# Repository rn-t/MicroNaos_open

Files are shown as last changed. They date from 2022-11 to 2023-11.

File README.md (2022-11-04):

# MicroNaos_open
マイクロマウスというロボット競技の、クラシックマウス部門用のロボットです。



## ディレクトリ
### DXF

基板外形のDXFファイルです

### firmware
STM32向けのソースコードです。主にC++で記述しています。STM32HAL、CMSIS、SEGGER-RTTなどのライブラリも含まれています。

### PCB
機体の大部分を構成しているプリント基板及び、その回路のファイルです。Kicadを用いて作成しました
公開するにあたってライセンスの問題がないように編集を行ったため、回路シンボルが基板発注時と少し異なっています。

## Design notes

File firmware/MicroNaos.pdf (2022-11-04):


19/04/2022

MicroNaos Project
Configuration Report

## 1. Description

### 1.1. Project

Project Name | MicroNaos
Board Name | custom
Generated with: | STM32CubeMX 6.5.0
Date | 04/19/2022

### 1.2. MCU

MCU Series | STM32F4
MCU Line | STM32F405/415
MCU name | STM32F405RGTx
MCU Package | LQFP64
MCU Pin number | 64

### 1.3. Core(s) information

Core(s) | Arm Cortex-M4

## 2. Pinout Configuration

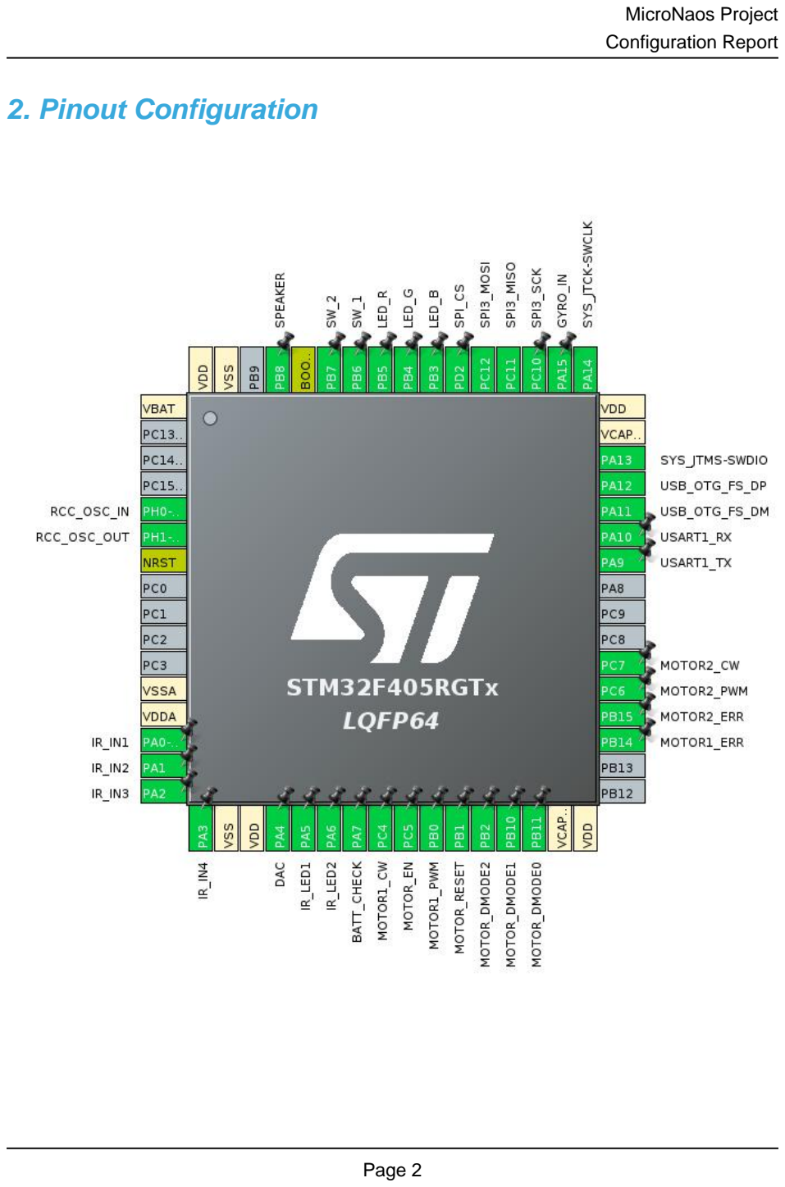
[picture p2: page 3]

## 3. Pins Configuration

Pin Number LQFP64 | Pin Name (function after reset) | Pin Type | Alternate Function(s) | Label
1 | VBAT | Power
5 | PH0-OSC_IN | I/O | RCC_OSC_IN
6 | PH1-OSC_OUT | I/O | RCC_OSC_OUT
7 | NRST | Reset
12 | VSSA | Power
13 | VDDA | Power
14 | PA0-WKUP | I/O | ADC1_IN0 | IR_IN1
15 | PA1 | I/O | ADC1_IN1 | IR_IN2
16 | PA2 | I/O | ADC1_IN2 | IR_IN3
17 | PA3 | I/O | ADC1_IN3 | IR_IN4
18 | VSS | Power
19 | VDD | Power
20 | PA4 | I/O | DAC_OUT1 | DAC
21 | PA5 | I/O | TIM2_CH1 | IR_LED1
22 | PA6 | I/O | TIM13_CH1 | IR_LED2
23 | PA7 | I/O | ADC1_IN7 | BATT_CHECK
24 | PC4 * | I/O | GPIO_Output | MOTOR1_CW
25 | PC5 * | I/O | GPIO_Output | MOTOR_EN
26 | PB0 | I/O | TIM3_CH3 | MOTOR1_PWM
27 | PB1 * | I/O | GPIO_Output | MOTOR_RESET
28 | PB2 * | I/O | GPIO_Output | MOTOR_DMODE2
29 | PB10 * | I/O | GPIO_Output | MOTOR_DMODE1
30 | PB11 * | I/O | GPIO_Output | MOTOR_DMODE0
31 | VCAP_1 | Power
32 | VDD | Power
35 | PB14 * | I/O | GPIO_Input | MOTOR1_ERR
36 | PB15 * | I/O | GPIO_Input | MOTOR2_ERR
37 | PC6 | I/O | TIM8_CH1 | MOTOR2_PWM
38 | PC7 * | I/O | GPIO_Output | MOTOR2_CW
42 | PA9 | I/O | USART1_TX
43 | PA10 | I/O | USART1_RX
44 | PA11 | I/O | USB_OTG_FS_DM
45 | PA12 | I/O | USB_OTG_FS_DP
46 | PA13 | I/O | SYS_JTMS-SWDIO
47 | VCAP_2 | Power
48 | VDD | Power

Pin Number LQFP64 | Pin Name (function after reset) | Pin Type | Alternate Function(s) | Label
49 | PA14 | I/O | SYS_JTCK-SWCLK
50 | PA15 * | I/O | GPIO_Input | GYRO_IN
51 | PC10 | I/O | SPI3_SCK
52 | PC11 | I/O | SPI3_MISO
53 | PC12 | I/O | SPI3_MOSI
54 | PD2 * | I/O | GPIO_Output | SPI_CS
55 | PB3 * | I/O | GPIO_Output | LED_B
56 | PB4 * | I/O | GPIO_Output | LED_G
57 | PB5 * | I/O | GPIO_Output | LED_R
58 | PB6 * | I/O | GPIO_Input | SW_1
59 | PB7 * | I/O | GPIO_Input | SW_2
60 | BOOT0 | Boot
61 | PB8 | I/O | TIM10_CH1 | SPEAKER
63 | VSS | Power
64 | VDD | Power

* The pin is affected with an I/O function

## 4. Clock Tree Configuration

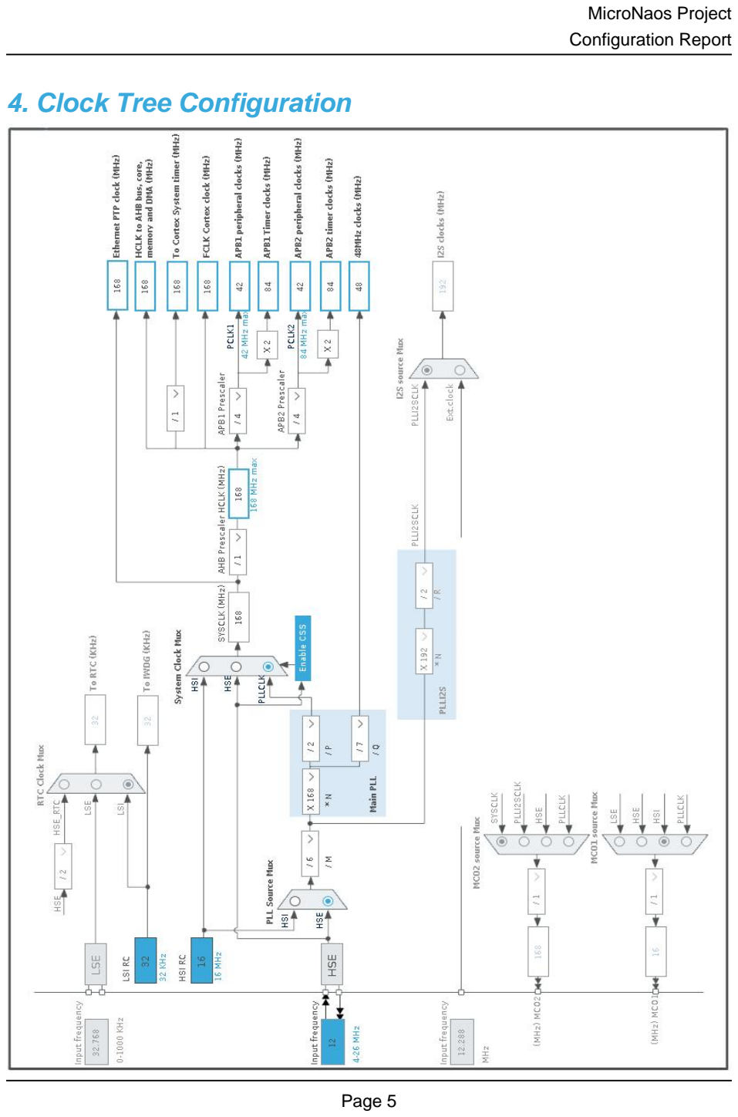
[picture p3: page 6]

## 5. Software Project

### 5.1. Project Settings

Name | Value
Project Name | MicroNaos
Project Folder | /home/hitomosi/MicroNaos/firmware
Toolchain / IDE | Makefile
Firmware Package Name and Version | STM32Cube FW_F4 V1.25.2
Application Structure | Advanced
Generate Under Root | No
Do not generate the main() | No
Minimum Heap Size | 0x200
Minimum Stack Size | 0x400

### 5.2. Code Generation Settings

Name | Value
STM32Cube MCU packages and embedded software | Copy only the necessary library files
Generate peripheral initialization as a pair of '.c/.h' files | No
Backup previously generated files when re-generating | No
Keep User Code when re-generating | Yes
Delete previously generated files when not re-generated | Yes
Set all free pins as analog (to optimize the power consumption) | No
Enable Full Assert | No

### 5.3. Advanced Settings - Generated Function Calls

Rank | Function Name | Peripheral Instance Name
1 | MX_GPIO_Init | GPIO
2 | SystemClock_Config | RCC
3 | MX_ADC1_Init | ADC1
4 | MX_DAC_Init | DAC
5 | MX_SPI3_Init | SPI3
6 | MX_TIM2_Init | TIM2
7 | MX_TIM10_Init | TIM10
8 | MX_TIM13_Init | TIM13
9 | MX_USART1_UART_Init | USART1
10 | MX_USB_DEVICE_Init | USB_DEVICE
11 | MX_TIM8_Init | TIM8

Rank | Function Name | Peripheral Instance Name
12 | MX_TIM3_Init | TIM3

## 6. Power Consumption Calculator report

### 6.1. Microcontroller Selection

Series | STM32F4
Line | STM32F405/415
MCU | STM32F405RGTx
Datasheet | DS8626_Rev8

### 6.2. Parameter Selection

Temperature | 25
Vdd | 3.3

### 6.3. Battery Selection

Battery | Li-SOCL2(A3400)
Capacity | 3400.0 mAh
Self Discharge | 0.08 %/month
Nominal Voltage | 3.6 V
Max Cont Current | 100.0 mA
Max Pulse Current | 200.0 mA
Cells in series | 1
Cells in parallel | 1

### 6.4. Sequence

Step | Step1 | Step2
Mode | RUN | STOP
Vdd | 3.3 | 3.3
Voltage Source | Battery | Battery
Range | Scale1-High | No Scale
Fetch Type | FLASH | n/a
CPU Frequency | 168 MHz | 0 Hz
Clock Configuration | HSE PLL | Regulator_LP Flash-PwrDwn
Clock Source Frequency | 4 MHz | 0 Hz
Peripherals
Additional Cons. | 0 mA | 0 mA
Average Current | 46 mA | 280 µA
Duration | 0.1 ms | 0.9 ms
DMIPS | 210.0 | 0.0
Ta Max | 98.02 | 104.96
Category | In DS Table | In DS Table

### 6.5. Results

Sequence Time | 1 ms | Average Current | 4.85 mA
Battery Life | 29 days, 4 hours | Average DMIPS | 210.0 DMIPS

### 6.6. Chart

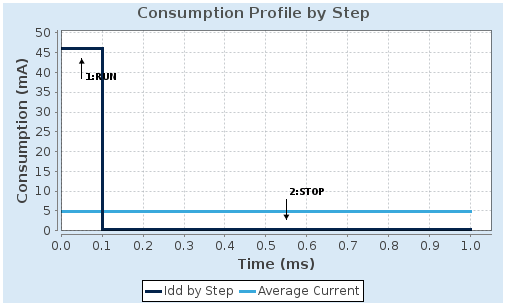
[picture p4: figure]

## 7. Peripherals and Middlewares Configuration

### 7.1. ADC1

mode: IN0
mode: IN1
mode: IN2
mode: IN3
mode: IN7
7.1.1. Parameter Settings:

ADCs_Common_Settings:

Mode | Independent mode
ADC_Settings:
Clock Prescaler | PCLK2 divided by 2
Resolution | 12 bits (15 ADC Clock cycles)
Data Alignment | Right alignment
Scan Conversion Mode | Disabled
Continuous Conversion Mode | Disabled
Discontinuous Conversion Mode | Disabled
DMA Continuous Requests | Disabled
End Of Conversion Selection | EOC flag at the end of single channel conversion
ADC_Regular_ConversionMode:
Number Of Conversion | 1
External Trigger Conversion Source | Regular Conversion launched by software
External Trigger Conversion Edge | None
Rank | 1
Channel | Channel 0
Sampling Time | 3 Cycles
ADC_Injected_ConversionMode:
Number Of Conversions | 0
WatchDog:
Enable Analog WatchDog Mode | false

### 7.2. DAC

mode: OUT1 Configuration
7.2.1. Parameter Settings:

DAC Out1 Settings:

Output Buffer | Enable
Trigger | None

### 7.3. RCC

High Speed Clock (HSE): Crystal/Ceramic Resonator
7.3.1. Parameter Settings:

System Parameters:

VDD voltage (V) | 3.3
Instruction Cache | Enabled
Prefetch Buffer | Enabled
Data Cache | Enabled
Flash Latency(WS) | 5 WS (6 CPU cycle)
RCC Parameters:
HSI Calibration Value | 16
HSE Startup Timout Value (ms) | 100
LSE Startup Timout Value (ms) | 5000
Power Parameters:
Power Regulator Voltage Scale | Power Regulator Voltage Scale 1

### 7.4. SPI3

Mode: Full-Duplex Master
7.4.1. Parameter Settings:

Basic Parameters:

Frame Format | Motorola
Data Size | 8 Bits
First Bit | MSB First
Clock Parameters:
Prescaler (for Baud Rate) | 8 *
Baud Rate | 5.25 MBits/s *
Clock Polarity (CPOL) | High *
Clock Phase (CPHA) | 2 Edge *
Advanced Parameters:
CRC Calculation | Disabled
NSS Signal Type | Software

### 7.5. SYS

Debug: Serial Wire
Timebase Source: SysTick

### 7.6. TIM2

Channel1: PWM Generation CH1
7.6.1. Parameter Settings:

Counter Settings:

Prescaler (PSC - 16 bits value) | 0
Counter Mode | Up
Counter Period (AutoReload Register - 32 bits value ) | 4294967295
Internal Clock Division (CKD) | No Division
auto-reload preload | Disable
Trigger Output (TRGO) Parameters:
Master/Slave Mode (MSM bit) | Disable (Trigger input effect not delayed)
Trigger Event Selection | Reset (UG bit from TIMx_EGR)
PWM Generation Channel 1:
Mode | PWM mode 1
Pulse (32 bits value) | 0
Output compare preload | Enable
Fast Mode | Disable
CH Polarity | High

### 7.7. TIM3

Channel3: PWM Generation CH3
7.7.1. Parameter Settings:

Counter Settings:

Prescaler (PSC - 16 bits value) | 420 - 1 *
Counter Mode | Up
Counter Period (AutoReload Register - 16 bits value ) | 1000 - 1 *
Internal Clock Division (CKD) | No Division
auto-reload preload | Disable
Trigger Output (TRGO) Parameters:

Master/Slave Mode (MSM bit) | Disable (Trigger input effect not delayed)
Trigger Event Selection | Reset (UG bit from TIMx_EGR)
PWM Generation Channel 3:
Mode | PWM mode 1
Pulse (16 bits value) | 500 - 1 *
Output compare preload | Enable
Fast Mode | Disable
CH Polarity | High

### 7.8. TIM8

Channel1: PWM Generation CH1
7.8.1. Parameter Settings:

Counter Settings:

Prescaler (PSC - 16 bits value) | 420 - 1 *
Counter Mode | Up
Counter Period (AutoReload Register - 16 bits value ) | 1000 - 1 *
Internal Clock Division (CKD) | No Division
Repetition Counter (RCR - 8 bits value) | 0
auto-reload preload | Disable
Trigger Output (TRGO) Parameters:
Master/Slave Mode (MSM bit) | Disable (Trigger input effect not delayed)
Trigger Event Selection | Reset (UG bit from TIMx_EGR)
Break And Dead Time management - BRK Configuration:
BRK State | Disable
BRK Polarity | High
Break And Dead Time management - Output Configuration:
Automatic Output State | Disable
Off State Selection for Run Mode (OSSR) | Disable
Off State Selection for Idle Mode (OSSI) | Disable
Lock Configuration | Off
PWM Generation Channel 1:
Mode | PWM mode 1
Pulse (16 bits value) | 500 - 1 *
Output compare preload | Enable
Fast Mode | Disable
CH Polarity | High
CH Idle State | Reset

### 7.9. TIM10

mode: Activated
Channel1: PWM Generation CH1
7.9.1. Parameter Settings:

Counter Settings:

Prescaler (PSC - 16 bits value) | 0
Counter Mode | Up
Counter Period (AutoReload Register - 16 bits value ) | 65535
Internal Clock Division (CKD) | No Division
auto-reload preload | Disable
PWM Generation Channel 1:
Mode | PWM mode 1
Pulse (16 bits value) | 0
Output compare preload | Enable
Fast Mode | Disable
CH Polarity | High

### 7.10. TIM13

mode: Activated
Channel1: PWM Generation CH1
7.10.1. Parameter Settings:

Counter Settings:

Prescaler (PSC - 16 bits value) | 0
Counter Mode | Up
Counter Period (AutoReload Register - 16 bits value ) | 65535
Internal Clock Division (CKD) | No Division
auto-reload preload | Disable
PWM Generation Channel 1:
Mode | PWM mode 1
Pulse (16 bits value) | 0
Output compare preload | Enable
Fast Mode | Disable
CH Polarity | High

### 7.11. USART1

Mode: Asynchronous
7.11.1. Parameter Settings:

Basic Parameters:

Baud Rate | 115200
Word Length | 8 Bits (including Parity)
Parity | None
Stop Bits | 1
Advanced Parameters:
Data Direction | Receive and Transmit
Over Sampling | 16 Samples

### 7.12. USB_OTG_FS

Mode: Device_Only
7.12.1. Parameter Settings:
Speed | Device Full Speed 12MBit/s
Low power | Disabled
Link Power Management | Disabled
VBUS sensing | Disabled
Signal start of frame | Disabled

### 7.13. USB_DEVICE

Class For FS IP: Human Interface Device Class (HID)
7.13.1. Parameter Settings:

Class Parameters:

HID_FS_BINTERVAL | 0xA *
Basic Parameters:
USBD_MAX_NUM_INTERFACES (Maximum number of supported interfaces) | 1
USBD_MAX_NUM_CONFIGURATION (Maximum number of supported configuration) | 1
USBD_MAX_STR_DESC_SIZ (Maximum size for the string descriptors) | 512
USBD_SELF_POWERED (Enabled self power) | Enabled

USBD_DEBUG_LEVEL (USBD Debug Level) | 0: No debug message
7.13.2. Device Descriptor:

Device Descriptor:

VID (Vendor IDentifier) | 1155
LANGID_STRING (Language Identifier) | English(United States)
MANUFACTURER_STRING (Manufacturer Identifier) | STMicroelectronics
Device Descriptor FS:
PID (Product IDentifier) | 22315
PRODUCT_STRING (Product Identifier) | STM32 Human interface
CONFIGURATION_STRING (Configuration Identifier) | HID Config
INTERFACE_STRING (Interface Identifier) | HID Interface

* User modified value

## 8. System Configuration

### 8.1. GPIO configuration

IP | Pin | Signal | GPIO mode | GPIO pull/up pull down | Max Speed | User Label
ADC1 | PA0-WKUP | ADC1_IN0 | Analog mode | No pull-up and no pull-down | n/a | IR_IN1
| PA1 | ADC1_IN1 | Analog mode | No pull-up and no pull-down | n/a | IR_IN2
| PA2 | ADC1_IN2 | Analog mode | No pull-up and no pull-down | n/a | IR_IN3
| PA3 | ADC1_IN3 | Analog mode | No pull-up and no pull-down | n/a | IR_IN4
| PA7 | ADC1_IN7 | Analog mode | No pull-up and no pull-down | n/a | BATT_CHECK
DAC | PA4 | DAC_OUT1 | Analog mode | No pull-up and no pull-down | n/a | DAC
RCC | PH0-OSC_IN | RCC_OSC_IN | n/a | n/a | n/a
| PH1-OSC_OUT | RCC_OSC_OUT | n/a | n/a | n/a
SPI3 | PC10 | SPI3_SCK | Alternate Function Push Pull | No pull-up and no pull-down | Very High *
| PC11 | SPI3_MISO | Alternate Function Push Pull | No pull-up and no pull-down | Very High *
| PC12 | SPI3_MOSI | Alternate Function Push Pull | No pull-up and no pull-down | Very High *
SYS | PA13 | SYS_JTMS-SWDIO | n/a | n/a | n/a
| PA14 | SYS_JTCK-SWCLK | n/a | n/a | n/a
TIM2 | PA5 | TIM2_CH1 | Alternate Function Push Pull | No pull-up and no pull-down | Low | IR_LED1
TIM3 | PB0 | TIM3_CH3 | Alternate Function Push Pull | No pull-up and no pull-down | Low | MOTOR1_PWM
TIM8 | PC6 | TIM8_CH1 | Alternate Function Push Pull | No pull-up and no pull-down | Low | MOTOR2_PWM
TIM10 | PB8 | TIM10_CH1 | Alternate Function Push Pull | No pull-up and no pull-down | Low | SPEAKER
TIM13 | PA6 | TIM13_CH1 | Alternate Function Push Pull | No pull-up and no pull-down | Low | IR_LED2
USART1 | PA9 | USART1_TX | Alternate Function Push Pull | No pull-up and no pull-down | Very High *
| PA10 | USART1_RX | Alternate Function Push Pull | No pull-up and no pull-down | Very High *
USB_OTG_ FS | PA11 | USB_OTG_FS_ DM | Alternate Function Push Pull | No pull-up and no pull-down | Very High *
| PA12 | USB_OTG_FS_ DP | Alternate Function Push Pull | No pull-up and no pull-down | Very High *
GPIO | PC4 | GPIO_Output | Output Push Pull | No pull-up and no pull-down | Low | MOTOR1_CW
| PC5 | GPIO_Output | Output Push Pull | No pull-up and no pull-down | Low | MOTOR_EN
| PB1 | GPIO_Output | Output Push Pull | No pull-up and no pull-down | Low | MOTOR_RESET

IP | Pin | Signal | GPIO mode | GPIO pull/up pull down | Max Speed | User Label
| PB2 | GPIO_Output | Output Push Pull | No pull-up and no pull-down | Low | MOTOR_DMODE2
| PB10 | GPIO_Output | Output Push Pull | No pull-up and no pull-down | Low | MOTOR_DMODE1
| PB11 | GPIO_Output | Output Push Pull | No pull-up and no pull-down | Low | MOTOR_DMODE0
| PB14 | GPIO_Input | Input mode | No pull-up and no pull-down | n/a | MOTOR1_ERR
| PB15 | GPIO_Input | Input mode | No pull-up and no pull-down | n/a | MOTOR2_ERR
| PC7 | GPIO_Output | Output Push Pull | No pull-up and no pull-down | Low | MOTOR2_CW
| PA15 | GPIO_Input | Input mode | No pull-up and no pull-down | n/a | GYRO_IN
| PD2 | GPIO_Output | Output Push Pull | No pull-up and no pull-down | Low | SPI_CS
| PB3 | GPIO_Output | Output Push Pull | No pull-up and no pull-down | Low | LED_B
| PB4 | GPIO_Output | Output Push Pull | No pull-up and no pull-down | Low | LED_G
| PB5 | GPIO_Output | Output Push Pull | No pull-up and no pull-down | Low | LED_R
| PB6 | GPIO_Input | Input mode | Pull-up * | n/a | SW_1
| PB7 | GPIO_Input | Input mode | Pull-up * | n/a | SW_2

### 8.2. DMA configuration

nothing configured in DMA service

### 8.3. NVIC configuration

8.3.1. NVIC
Interrupt Table | Enable | Preenmption Priority | SubPriority
Non maskable interrupt | true | 0 | 0
Hard fault interrupt | true | 0 | 0
Memory management fault | true | 0 | 0
Pre-fetch fault, memory access fault | true | 0 | 0
Undefined instruction or illegal state | true | 0 | 0
System service call via SWI instruction | true | 0 | 0
Debug monitor | true | 0 | 0
Pendable request for system service | true | 0 | 0
System tick timer | true | 0 | 0
TIM3 global interrupt | true | 0 | 0
TIM8 break interrupt and TIM12 global interrupt | true | 0 | 0
TIM8 update interrupt and TIM13 global interrupt | true | 0 | 0
TIM8 trigger and commutation interrupts and TIM14 global interrupt | true | 0 | 0
TIM8 capture compare interrupt | true | 0 | 0
USB On The Go FS global interrupt | true | 0 | 0
PVD interrupt through EXTI line 16 | unused
Flash global interrupt | unused
RCC global interrupt | unused
ADC1, ADC2 and ADC3 global interrupts | unused
TIM1 update interrupt and TIM10 global interrupt | unused
TIM2 global interrupt | unused
USART1 global interrupt | unused
SPI3 global interrupt | unused
TIM6 global interrupt, DAC1 and DAC2 underrun error interrupts | unused
FPU global interrupt | unused
8.3.2. NVIC Code generation
Enabled interrupt Table | Select for init sequence ordering | Generate IRQ handler | Call HAL handler
Non maskable interrupt | false | true | false
Hard fault interrupt | false | true | false
Memory management fault | false | true | false
Pre-fetch fault, memory access fault | false | true | false
Undefined instruction or illegal state | false | true | false

Enabled interrupt Table | Select for init sequence ordering | Generate IRQ handler | Call HAL handler
System service call via SWI instruction | false | true | false
Debug monitor | false | true | false
Pendable request for system service | false | true | false
System tick timer | false | true | true
TIM3 global interrupt | false | true | true
TIM8 break interrupt and TIM12 global interrupt | false | true | true
TIM8 update interrupt and TIM13 global interrupt | false | true | true
TIM8 trigger and commutation interrupts and TIM14 global interrupt | false | true | true
TIM8 capture compare interrupt | false | true | true
USB On The Go FS global interrupt | false | true | true

* User modified value

## 9. System Views

9.1. Category view
9.1.1. Current

## 10. Docs & Resources

Type | Link
Presentations | https://www.st.com/resource/en/product_presentation/stm32-stm8_embedded_software_solutions.pdf
Presentations | https://www.st.com/resource/en/product_presentation/stm32_eval-tools_portfolio.pdf
Presentations | https://www.st.com/resource/en/product_presentation/stm32_stm8_functi onal-safety-packages.pdf
Presentations | https://www.st.com/resource/en/product_presentation/stm32-stm8_software_development_tools.pdf
Training Material | https://www.st.com/resource/en/sales_guide/sg_sc2154.pdf
Flyers | https://www.st.com/resource/en/flyer/flnucleolrwan.pdf
Flyers | https://www.st.com/resource/en/flyer/flstm32nucleo.pdf
Flyers | https://www.st.com/resource/en/flyer/flstmcsuite.pdf
Flyers | https://www.st.com/resource/en/flyer/flstm32trust.pdf
Product Certifications | https://www.st.com/resource/en/certification_document/stm32_authentication_can.pdf
Application Notes | https://www.st.com/resource/en/application_note/an1181-electrostatic-discharge-sensitivity-measurement-stmicroelectronics.pdf
Application Notes | https://www.st.com/resource/en/application_note/an1709-emc-design-guide-for-stm8-stm32-and-legacy-mcus-stmicroelectronics.pdf
Application Notes | https://www.st.com/resource/en/application_note/an2606-stm32-microcontroller-system-memory-boot-mode-stmicroelectronics.pdf
Application Notes | https://www.st.com/resource/en/application_note/an2639-soldering-recommendations-and-package-information-for-leadfree-ecopack-mcus-and-mpus-stmicroelectronics.pdf
Application Notes | https://www.st.com/resource/en/application_note/an2834-how-to-get-the-best-adc-accuracy-in-stm32-microcontrollers-stmicroelectronics.pdf
Application Notes | https://www.st.com/resource/en/application_note/an2867-oscillator-design-guide-for-stm8afals-stm32-mcus-and-mpus-stmicroelectronics.pdf
Application Notes | https://www.st.com/resource/en/application_note/an2945-stm8s-and-

| stm32-mcus-a-consistent-832bit-product-line-for-painless-migration-stmicroelectronics.pdf
Application Notes | https://www.st.com/resource/en/application_note/an3070-managing-the-driver-enable-signal-for-rs485-and-iolink-communications-with-the-stm32s-usart-stmicroelectronics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
Application Notes | https://www.st.com/resource/en/application_note/an3126-audio-and-waveform-generation-using-the-dac-in-stm32-products-stmicroelectronics.pdf
Application Notes | https://www.st.com/resource/en/application_note/an3154-can-protocol-used-in-the-stm32-bootloader-stmicroelectronics.pdf
Application Notes | https://www.st.com/resource/en/application_note/an3155-usart-protocol-used-in-the-stm32-bootloader-stmicroelectronics.pdf
Application Notes | https://www.st.com/resource/en/application_note/an3156-usb-dfu-protocol-used-in-the-stm32-bootloader-stmicroelectronics.pdf
Application Notes | https://www.st.com/resource/en/application_note/an3364-migration-and-compatibility-guidelines-for-stm32-microcontroller-applications-stmicroelectronics.pdf
Application Notes | https://www.st.com/resource/en/application_note/an3371-using-the-hardware-realtime-clock-rtc-in-stm32-f0-f2-f3-f4-and-l1-series-of-mcus-stmicroelectronics.pdf
Application Notes | https://www.st.com/resource/en/application_note/an3997-audio-playback-and-recording-using-the-stm32f4discovery-stmicroelectronics.pdf
Application Notes | https://www.st.com/resource/en/application_note/an3998-pdm-audio-software-decoding-on-stm32-microcontrollers-stmicroelectronics.pdf
Application Notes | https://www.st.com/resource/en/application_note/an4013-stm32-crossseries-timer-overview-stmicroelectronics.pdf
Application Notes | https://www.st.com/resource/en/application_note/an4031-using-the-stm32f2-stm32f4-and-stm32f7-series-dma-controller-stmicroelectronics.pdf
Application Notes | https://www.st.com/resource/en/application_note/an4073-how-to-improve-adc-accuracy-when-using-stm32f2xx-and-stm32f4xx-microcontrollers-stmicroelectronics.pdf
Application Notes | https://www.st.com/resource/en/application_note/an4076-two-or-three-

| shunt-resistor-based-current-sensing-circuit-design-in-3phase-inverters-stmicroelectronics.pdf
Application Notes | https://www.st.com/resource/en/application_note/an4221-i2c-protocol-used-in-the-stm32-bootloader-stmicroelectronics.pdf
Application Notes | https://www.st.com/resource/en/application_note/an4229-how-to-implement-a-vocoder-solution-using-stm32-microcontrollers-stmicroelectronics.pdf
Application Notes | https://www.st.com/resource/en/application_note/an4230-stm32-microcontroller-random-number-generation-validation-using-the-nist-statistical-test-suite-stmicroelectro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
Application Notes | https://www.st.com/resource/en/application_note/an4277-using-stm32-device-pwm-shutdown-features-for-motor-control-and-digital-power-conversion-stmicroelectronics.pdf
Application Notes | https://www.st.com/resource/en/application_note/an4286-spi-protocol-used-in-the-stm32-bootloader-stmicroelectronics.pdf
Application Notes | https://www.st.com/resource/en/application_note/an4488-getting-started-with-stm32f4xxxx-mcu-hardware-development-stmicroelectronics.pdf
Application Notes | https://www.st.com/resource/en/application_note/an4566-extending-the-dac-performance-of-stm32-microcontrollers-stmicroelectronics.pdf
Application Notes | https://www.st.com/resource/en/application_note/an4640-peripherals-interconnections-on-stm32f4057xx-stm32f4157xx-stm32f42xxx-stm32f43xxx-stm32f446xx-and-stm32f469479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
Application Notes | https://www.st.com/resource/en/application_note/an4655-virtually-increasing-the-number-of-serial-communication-peripherals-in-stm32-applications-stmicroelectronics.p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
Application Notes | https://www.st.com/resource/en/application_note/an4739-stm32cube-firmware-examples-for-stm32f4-series-stmicroelectronics.pdf
Application Notes | https://www.st.com/resource/en/application_note/an4750-handling-of-soft-errors-in-stm32-applications-stmicroelectronics.pdf
Application Notes | https://www.st.com/resource/en/application_note/an4759-using-the-hardware-realtime-clock-rtc-and-the-tamper-management-unit-tamp-with-stm32-microcontrollers-stmicroe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
Application Notes | https://www.st.com/resource/en/application_note/an4776-generalpurpose-

| timer-cookbook-for-stm32-microcontrollers-stmicroelectronics.pdf
Application Notes | https://www.st.com/resource/en/application_note/an4803-highspeed-si-simulations-using-ibis-and-boardlevel-simulations-using-hyperlynx-si-on-stm32-mcus-and-mpus-stmic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
Application Notes | https://www.st.com/resource/en/application_note/an4821-migrating-from-stm32f405415-line-and-stm32f407417-line-to-stm32l4-series-and-stm32l4-series-microcontrollers-s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
Application Notes | https://www.st.com/resource/en/application_note/an4838-managing-memory-protection-unit-in-stm32-mcus-stmicroelectronics.pdf
Application Notes | https://www.st.com/resource/en/application_note/an4850-stm32-mcus-spreadspectrum-clock-generation-principles-properties-and-implementation-stmicroelectronics.pdf
Application Notes | https://www.st.com/resource/en/application_note/an4879-usb-hardware-and-pcb-guidelines-using-stm32-mcus-stmicroelectronics.pdf
Application Notes | https://www.st.com/resource/en/application_note/an4908-stm32-usart-automatic-baud-rate-detection-stmicroelectronics.pdf
Application Notes | https://www.st.com/resource/en/application_note/an4989-stm32-microcontroller-debug-toolbox-stmicroelectronics.pdf
Application Notes | https://www.st.com/resource/en/application_note/an4995-using-an-electromyogram-technique-to-detect-muscle-activity-stmicroelectronics.pdf
Application Notes | https://www.st.com/resource/en/application_note/an5027-interfacing-pdm-digital-microphones-using-stm32-mcus-and-mpus-stmicroelectronics.pdf
Application Notes | https://www.st.com/resource/en/application_note/an5036-thermal-management-guidelines-for-stm32-applications-stmicroelectronics.pdf
Application Notes | https://www.st.com/resource/en/application_note/an5073-receiving-spdif-audio-stream-with-the-stm32f4f7h7-series-stmicroelectronics.pdf
Application Notes | https://www.st.com/resource/en/application_note/an5156-introduction-to-stm32-microcontrollers-security-stmicroelectronics.pdf
Application Notes | https://www.st.com/resource/en/application_note/an5225-usb-typec-power-delivery-using-stm32-mcus-and-mpus-stmicroelectronics.pdf
Application Notes | https://www.st.com/resource/en/application_note/an5543-enhanced- methods-to-handle-spi-communication-on-stm32-devices-

| stmicroelectronics.pdf
Application Notes | https://www.st.com/resource/en/application_note/an4899-stm32-microcontroller-gpio-configuration-for-hardware-settings-and-lowpower-consumption-stmicroelectronics.pdf
Application Notes for related Tools & Software | https://www.st.com/resource/en/application_note/an1202_freertos_guide-freertos-guide-stmicroelectronics.pdf
Application Notes for related Tools & Software | https://www.st.com/resource/en/application_note/an1602_semihosting_in_truestudio-how-to-do-semihosting-in-truestudio-stmicroelectronics.pdf
Application Notes for related Tools & Software | https://www.st.com/resource/en/application_note/an1801_stm32cubeprogrammer_in_truestudio-installing-stm32cubeprogrammer-in-truestudio-stmicroelectronics.pdf
Application Notes for related Tools & Software | https://www.st.com/resource/en/application_note/atollic_editing_keyboard_shortcuts-atollic-editing-keyboard-shortcuts-stmicroelectronics.pdf
Application Notes for related Tools & Software | https://www.st.com/resource/en/application_note/iar_to_atollic_truestudio_migration_guide-truestudio-for-arm-migration-guide-iar-embedded-workbench-to-truestudio-stm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
Application Notes for related Tools & Software | https://www.st.com/resource/en/application_note/stm32cubemx_installation_in_truestudio-stm32cubemx-installation-in-truestudio-stmicroelectronics.pdf
Application Notes for related Tools & Software | https://www.st.com/resource/en/application_note/an2656-stm32f10xxx-lcd-glass-driver-firmware-stmicroelectronics.pdf
Application Notes for related Tools & Software | https://www.st.com/resource/en/application_note/an2790-tft-lcd-interfacing-with-the-highdensity-stm32f10xxx-fsmc-stmicroelectronics.pdf
Application Notes for related Tools & Software | https://www.st.com/resource/en/application_note/an3078-stm32-inapplication-programming-over-the-ic-bus-stmicroelectronics.pdf
Application Notes for related Tools & Software | https://www.st.com/resource/en/application_note/an3116-stm32s-adc-modes-and-their-applications-stmicroelectronics.pdf

Application Notes for related Tools & Software | https://www.st.com/resource/en/application_note/an3174-implementing-receivers-for-infrared-remote-control-protocols-using-stm32f10xxx-microcontrollers-stmicroelectro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
Application Notes for related Tools & Software | https://www.st.com/resource/en/application_note/an3241-qvga-tftlcd-direct-drive-using-the-stm32f10xx-fsmc-peripheral-stmicroelectronics.pdf
Application Notes for related Tools & Software | https://www.st.com/resource/en/application_note/an3307-guidelines-for-obtaining-iec-60335-class-b-certification-for-any-stm32-application-stmicroelectronics.pdf
Application Notes for related Tools & Software | https://www.st.com/resource/en/application_note/an3364-migration-and-compatibility-guidelines-for-stm32-microcontroller-applications-stmicroelectronics.pdf
Application Notes for related Tools & Software | https://www.st.com/resource/en/application_note/an3965-stm32f40xstm32f41x-inapplication-programming-using-the-usart-stmicroelectronics.pdf
Application Notes for related Tools & Software | https://www.st.com/resource/en/application_note/an3969-eeprom-emulation-in-stm32f40xstm32f41x-microcontrollers-stmicroelectronics.pdf
Application Notes for related Tools & Software | https://www.st.com/resource/en/application_note/an3988-clock-configuration-tool-for-stm32f40xx41xx427x437x-microcontrollers-stmicroelectronics.pdf
Application Notes for related Tools & Software | https://www.st.com/resource/en/application_note/an3990-upgrading-stm32f4discovery-board-firmware-using-a-usb-key-stmicroelectronics.pdf
Application Notes for related Tools & Software | https://www.st.com/resource/en/application_note/an3997-audio-playback-and-recording-using-the-stm32f4discovery-stmicroelectronics.pdf
Application Notes for related Tools & Software | https://www.st.com/resource/en/application_note/an3998-pdm-audio-software-decoding-on-stm32-microcontrollers-stmicroelectronics.pdf
Application Notes for related Tools & Software | https://www.st.com/resource/en/application_note/an4044-floating-point-unit-demonstration-on-stm32-microcontrollers-stmicroelectronics.pdf
Application Notes | https://www.st.com/resource/en/application_note/an4187-using-the-crc-

for related Tools & Software | peripheral-in-the-stm32-family-stmicroelectronics.pdf
Application Notes for related Tools & Software | https://www.st.com/resource/en/application_note/an4323-getting-started-with-stemwin-library-stmicroelectronics.pdf
Application Notes for related Tools & Software | https://www.st.com/resource/en/application_note/an4365-using-stm32f4-mcu-power-modes-with-best-dynamic-efficiency-stmicroelectronics.pdf
Application Notes for related Tools & Software | https://www.st.com/resource/en/application_note/an4435-guidelines-for-obtaining-ulcsaiec-607301603351-class-b-certification-in-any-stm32-application-stmicroelectroni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
Application Notes for related Tools & Software | https://www.st.com/resource/en/application_note/an4457-implementing-an-emulated-uart-on-stm32f4-microcontrollers-stmicroelectronics.pdf
Application Notes for related Tools & Software | https://www.st.com/resource/en/application_note/an4499-stm32--nrf51822-bluetooth-low-energy-system-solution-stmicroelectronics.pdf
Application Notes for related Tools & Software | https://www.st.com/resource/en/application_note/an4502-stm32-smbuspmbus-embedded-software-expansion-for-stm32cube-stmicroelectronics.pdf
Application Notes for related Tools & Software | https://www.st.com/resource/en/application_note/an4657-stm32-inapplication-programming-iap-using-the-usart-stmicroelectronics.pdf
Application Notes for related Tools & Software | https://www.st.com/resource/en/application_note/an4666-parallel-synchronous-transmission-using-gpio-and-dma-stmicroelectronics.pdf
Application Notes for related Tools & Software | https://www.st.com/resource/en/application_note/an4678-full-duplex-spi-emulation-for-stm32f4-microcontrollers-stmicroelectronics.pdf
Application Notes for related Tools & Software | https://www.st.com/resource/en/application_note/an4701-proprietary-code-readout-protection-on-microcontrollers-of-the-stm32f4-series-stmicroelectronics.pdf

Application Notes
for related Tools

https://www.st.com/resource/en/application_note/an4739-stm32cubefirmware-examples-for-stm32f4-series-stmicroelectronics.pdf

& Software
Application Notes for related Tools & Software | https://www.st.com/resource/en/application_note/an4758-proprietary-code-readout-protection-on-stm32l4-stm32l4-stm32g4-and-stm32wb-series-mcus-stmicroelectronics.pdf
Application Notes for related Tools & Software | https://www.st.com/resource/en/application_note/an4759-using-the-hardware-realtime-clock-rtc-and-the-tamper-management-unit-tamp-with-stm32-microcontrollers-stmicroe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
Application Notes for related Tools & Software | https://www.st.com/resource/en/application_note/an4841-digital-signal-processing-for-stm32-microcontrollers-using-cmsis-stmicroelectronics.pdf
Application Notes for related Tools & Software | https://www.st.com/resource/en/application_note/an4968-proprietary-code-read-out-protection-pcrop-on-stm32f72xxx-and-stm32f73xxx-microcontrollers-stmicroelectronics.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
Application Notes for related Tools & Software | https://www.st.com/resource/en/application_note/an5054-secure-programming-using-stm32cubeprogrammer-stmicroelectronics.pdf
Application Notes for related Tools & Software | https://www.st.com/resource/en/application_note/an5056-integration-guide-for-the-xcubesbsfu-stm32cube-expansion-package-stmicroelectronics.pdf
Application Notes for related Tools & Software | https://www.st.com/resource/en/application_note/an5143-how-to-migrate-motor-control-application-software-from-sdk-v43-to-sdk-v5x-stmicroelectronics.pdf
Application Notes for related Tools & Software | https://www.st.com/resource/en/application_note/an5166-guidelines-for-control-and-customization-of-power-boards-with-stm32-mc-sdk-v50-stmicroelectronics.pdf
Application Notes for related Tools & Software | https://www.st.com/resource/en/application_note/an5360-getting-started-with-projects-based-on-the-stm32mp1-series-in-stm32cubeide-stmicroelectronics.pdf
Application Notes for related Tools & Software | https://www.st.com/resource/en/application_note/an5361-getting-started-with-projects-based-on-dualcore-stm32h7-microcontrollers-in-stm32cubeide-stmicroelectronics.pd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
Application Notes for related Tools & Software | https://www.st.com/resource/en/application_note/an5394-getting-started-with-projects-based-on-the-stm32l5-series-in-stm32cubeide-stmicroelectronics.pdf

Application Notes for related Tools & Software | https://www.st.com/resource/en/application_note/an5418-how-to-build-a-simple-usbpd-sink-application-with-stm32cubemx-stmicroelectronics.pdf
Application Notes for related Tools & Software | https://www.st.com/resource/en/application_note/an5426-migrating-graphics-middleware-projects-from-stm32cubemx-540-to-stm32cubemx-550-stmicroelectronics.pdf
Application Notes for related Tools & Software | https://www.st.com/resource/en/application_note/an5464-position-control-of-a-threephase-permanent-magnet-motor-using-xcubemcsdk-or-xcubemcsdkful-stmicroelectronics.p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
Application Notes for related Tools & Software | https://www.st.com/resource/en/application_note/an5564-getting-started-with-projects-based-on-dualcore-stm32wl-microcontrollers-in-stm32cubeide-stmicroelectronics.pd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
Application Notes for related Tools & Software | https://www.st.com/resource/en/application_note/an5698-adapting-the-xcubestl-functional-safety-package-for-stm32-iec-61508-compliant-to-other-safety-standards-stmicr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
Application Notes for related Tools & Software | https://www.st.com/resource/en/application_note/an5731-stm32cubemx-and-stm32cubeide-threadsafe-solution-stmicroelectronics.pdf
Errata Sheets | https://www.st.com/resource/en/errata_sheet/es0182-stm32f405407xx-and-stm32f415417xx-device-limitations-stmicroelectronics.pdf
Datasheet | https://www.st.com/resource/en/datasheet/dm00037051.pdf
Programming Manuals | https://www.st.com/resource/en/programming_manual/pm0214-stm32-cortexm4-mcus-and-mpus-programming-manual-stmicroelectronics.pdf
Reference Manuals | https://www.st.com/resource/en/reference_manual/rm0090-stm32f405415-stm32f407417-stm32f427437-and-stm32f429439-advanced-armbased-32bit-mcus-stmicroelectronics.pdf
Technical Notes & Articles | https://www.st.com/resource/en/technical_note/tn0516-overview-of-the-stm32f0xf100xxf103xx-and-stm32f2xxf30xf4xx-mcus-pmsm-singledual-foc-sdk-v40-stmicroelectronics.p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
Technical Notes & Articles | https://www.st.com/resource/en/technical_note/tn1163-description-of-wlcsp-for-microcontrollers-and-recommendations-for-its-use-stmicroelectronics.pdf

Technical Notes
& Articles

https://www.st.com/resource/en/technical_note/tn1204-tape-and-reelshipping-media-for-stm32-microcontrollers-in-bga-packages-

| stmicroelectronics.pdf
Technical Notes & Articles | https://www.st.com/resource/en/technical_note/tn1205-tape-and-reel-shipping-media-for-stm8-and-stm32-microcontrollers-in-fpn-packages-stmicroelectronics.pdf
Technical Notes & Articles | https://www.st.com/resource/en/technical_note/tn1206-tape-and-reel-shipping-media-for-stm8-and-stm32-microcontrollers-in-qfp-packages-stmicroelectronics.pdf
Technical Notes & Articles | https://www.st.com/resource/en/technical_note/tn1207-tape-and-reel-shipping-media-for-stm8-and-stm32-microcontrollers-in-so-packages-stmicroelectronics.pdf
Technical Notes & Articles | https://www.st.com/resource/en/technical_note/tn1208-tape-and-reel-shipping-media-for-stm8-and-stm32-microcontrollers-in-tssop-and-ssop-packages-stmicroelectronics.p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

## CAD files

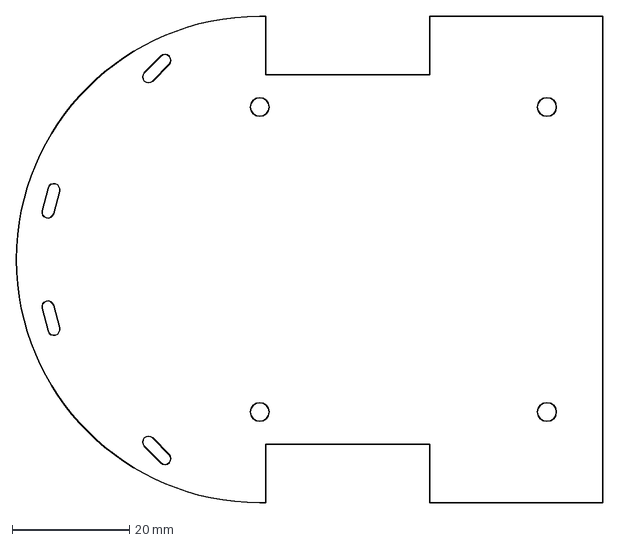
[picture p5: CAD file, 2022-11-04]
DXF/Kiban.dxf
100.0 x 83.0 mm

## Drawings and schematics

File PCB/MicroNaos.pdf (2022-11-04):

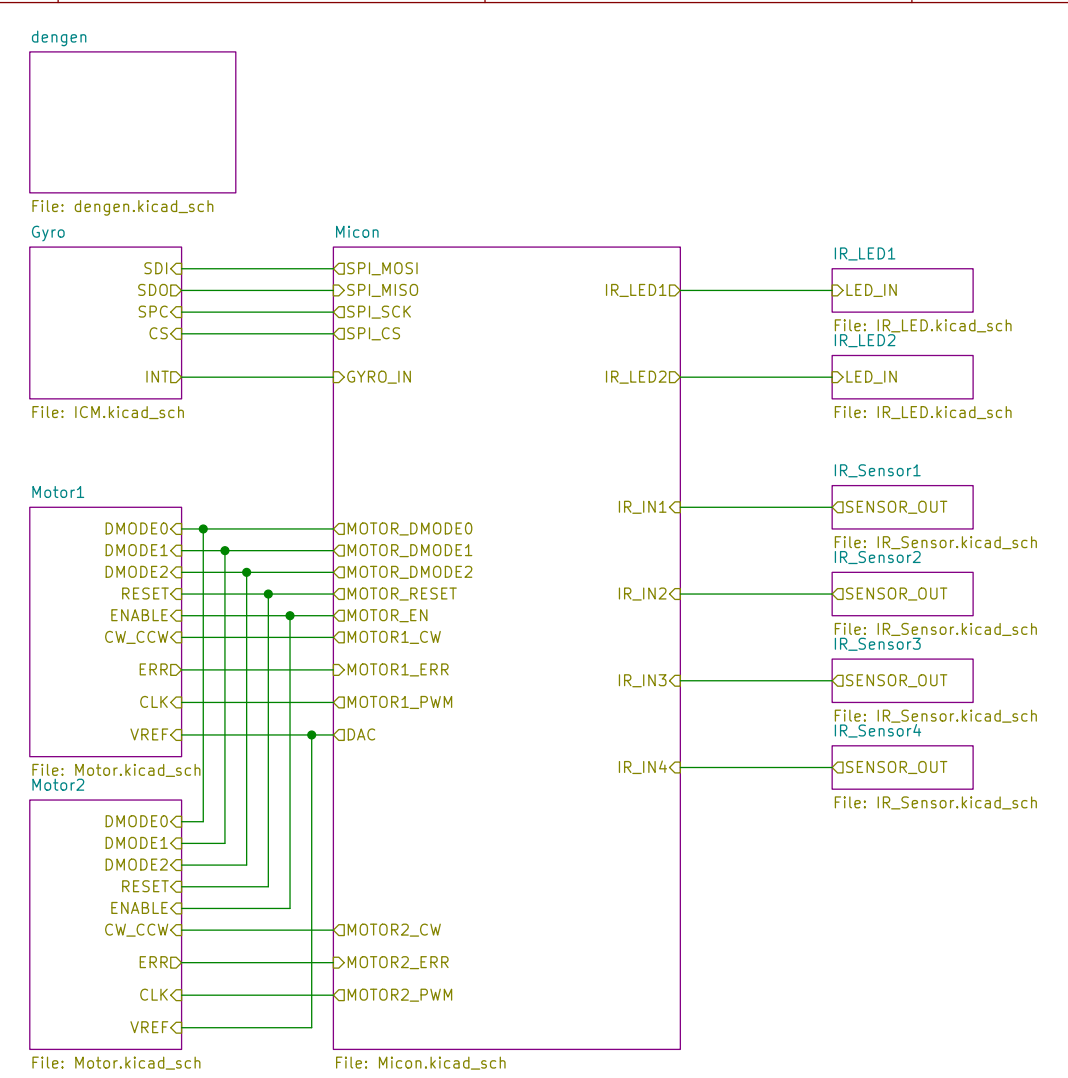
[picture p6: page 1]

INT CS Gyro File: ICM.kicad_sch VREF DMODE0 DMODE1 DMODE2 RESET CLK

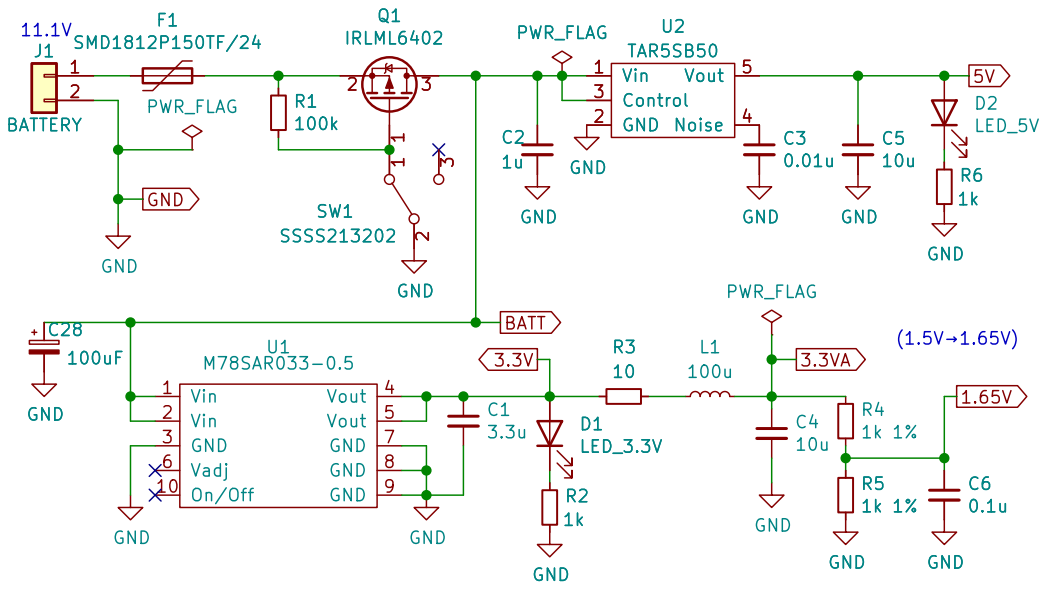
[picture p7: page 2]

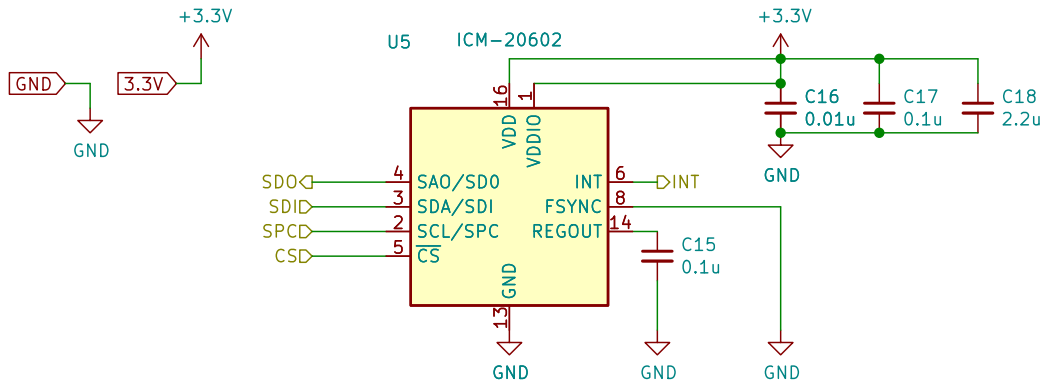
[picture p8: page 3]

1 GND 13 REGOUT 14 VDD 16 SCL/SPC 2 SDA/SDI 3 SAO/SD0 4 ~{CS} 5

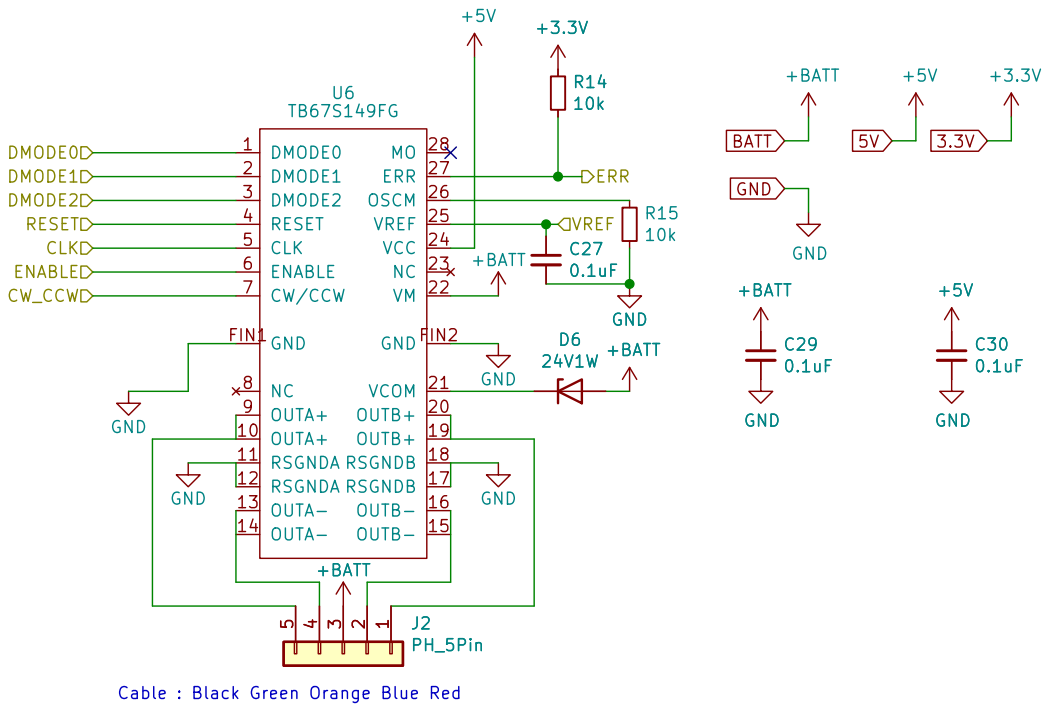
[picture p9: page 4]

BATT Cable : Black Green Orange Blue Red

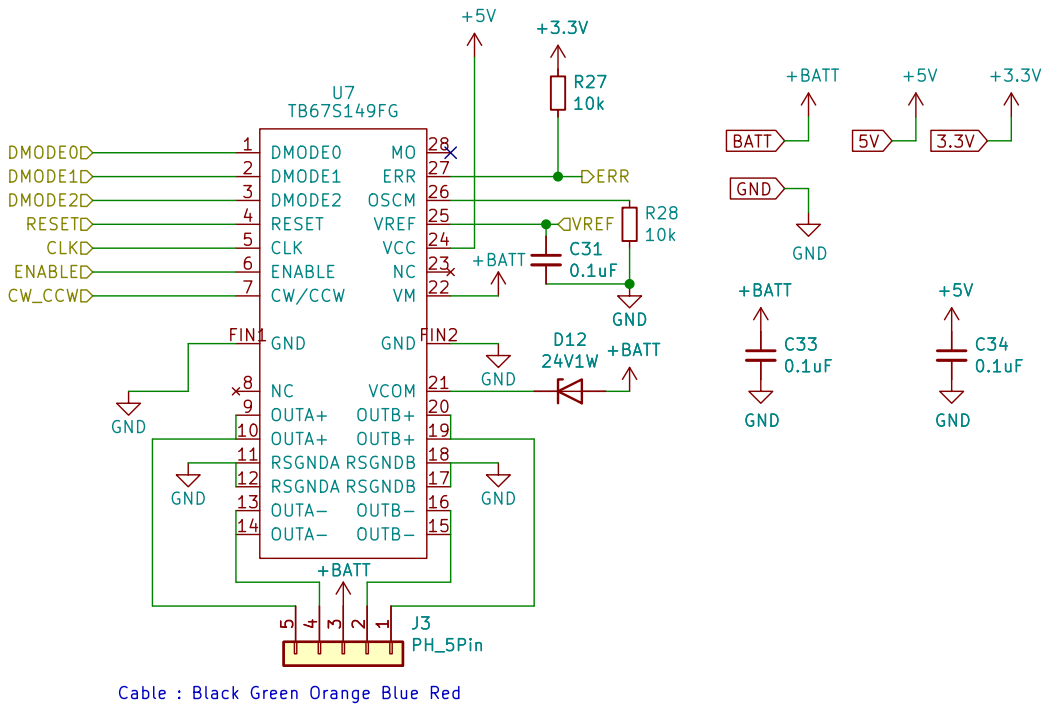
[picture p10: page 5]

BATT Cable : Black Green Orange Blue Red

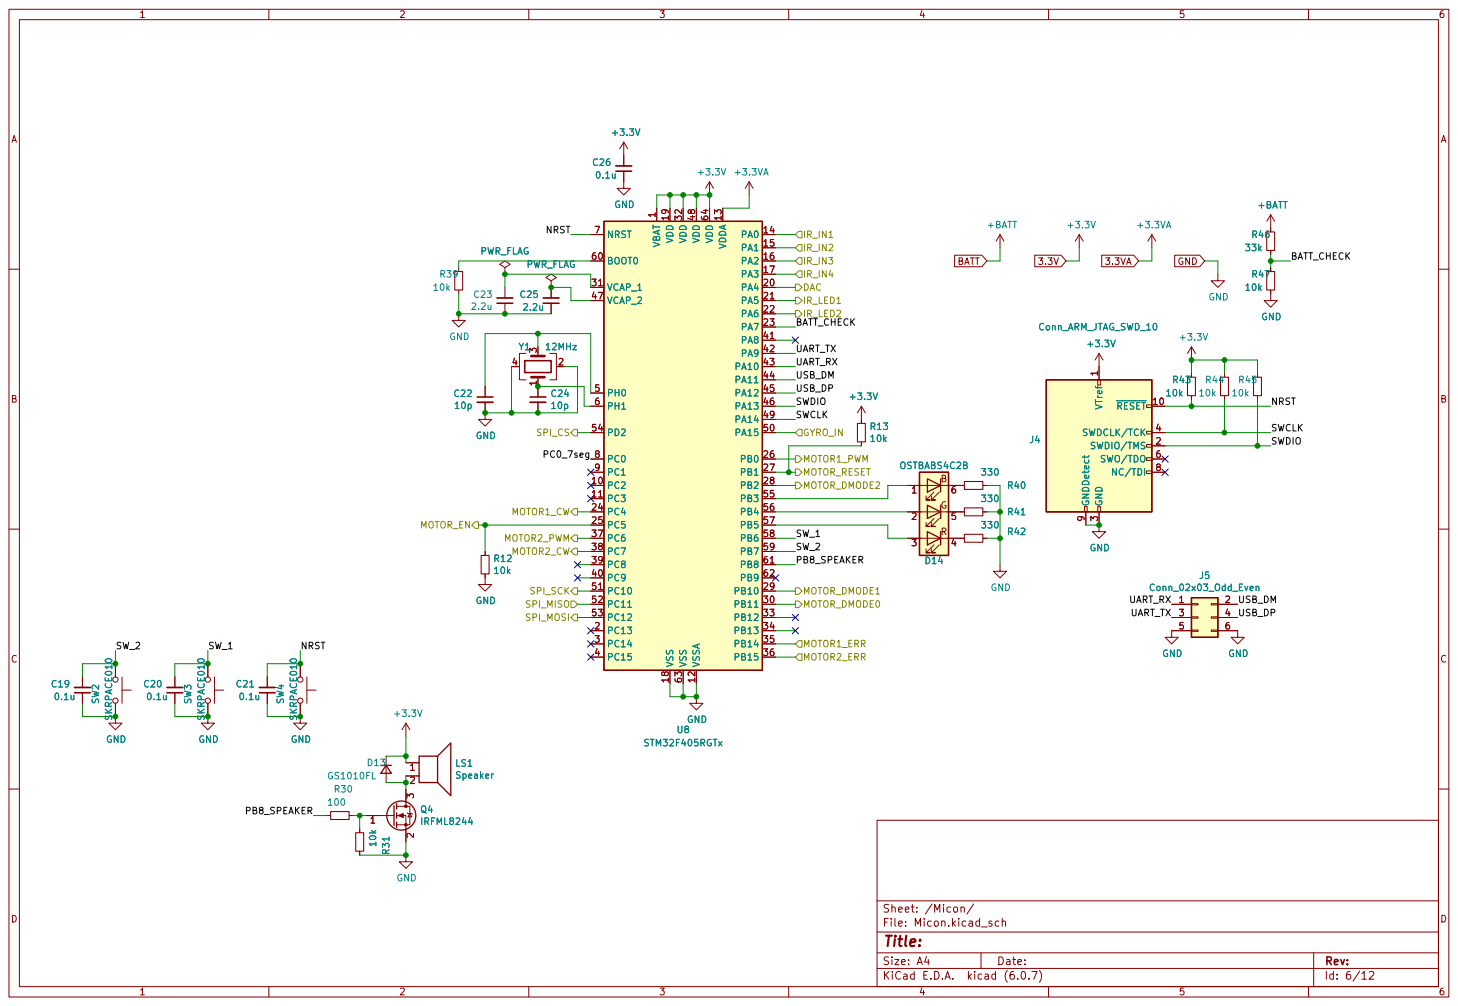
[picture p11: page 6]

1 PC2 10 PC3 11 VSSA 12 VDDA 13 PA0 14 PA1 15 PA2 16 PA3 17 VSS 18 VDD 19 PC13 2 PA4 20 PA5 21 PA6 22 PA7 23 PC4 24 PC5 25 PB0 26 PB1 27 PB2 28 PB10 29 PC14 3 PB11 30 VCAP_1 31 VDD 32 PB12 33 PB13 34 PB14 35 PB15 36 PC6 37 PC7 38 PC8 39 PC15 4 PC9 40 PA8 41 PA9 42 PA10 43 PA11 44 PA12 45 PA13 46 VCAP_2 47 VDD 48 PA14 49 PH0 5 PA15 50 PC10 51 PC11 52 PC12 53 PD2 54 PB3 55 PB4 56 PB5 57 PB6 58 PB7 59 PH1 6 BOOT0 60 PB8 61 PB9 62 VSS 63 VDD 64 NRST 7 PC0 8 PC1 9 U8 STM32F405RGTx

1 PC2 10 PC3 11 VSSA 12 VDDA 13 PA0 14 PA1 15 PA2 16 PA3 17 VSS 18 VDD 19 PC13 2 PA4 20 PA5 21 PA6 22 PA7 23 PC4 24 PC5 25 PB0 26 PB1 27 PB2 28 PB10 29 PC14 3 PB11 30 VCAP_1 31 VDD 32 PB12 33 PB13 34 PB14 35 PB15 36 PC6 37 PC7 38 PC8 39 PC15 4 PC9 40 PA8 41 PA9 42 PA10 43 PA11 44 PA12 45 PA13 46 VCAP_2 47 VDD 48 PA14 49 PH0 5 PA15 50 PC10 51 PC11 52 PC12 53 PD2 54 PB3 55 PB4 56 PB5 57 PB6 58 PB7 59 PH1 6 BOOT0 60 PB8 61 PB9 62 VSS 63 VDD 64 NRST 7 PC0 8 PC1 9 GND

3 SWDCLK/TCK 4 SWO/TDO 6 NC/TDI 8 GNDDetect 9 +3.3V GND

3 SWDCLK/TCK 4 SWO/TDO 6 NC/TDI 8 GNDDetect 9

File: Micon.kicad_sch Sheet: /Micon/
Id: 6/12 Title:

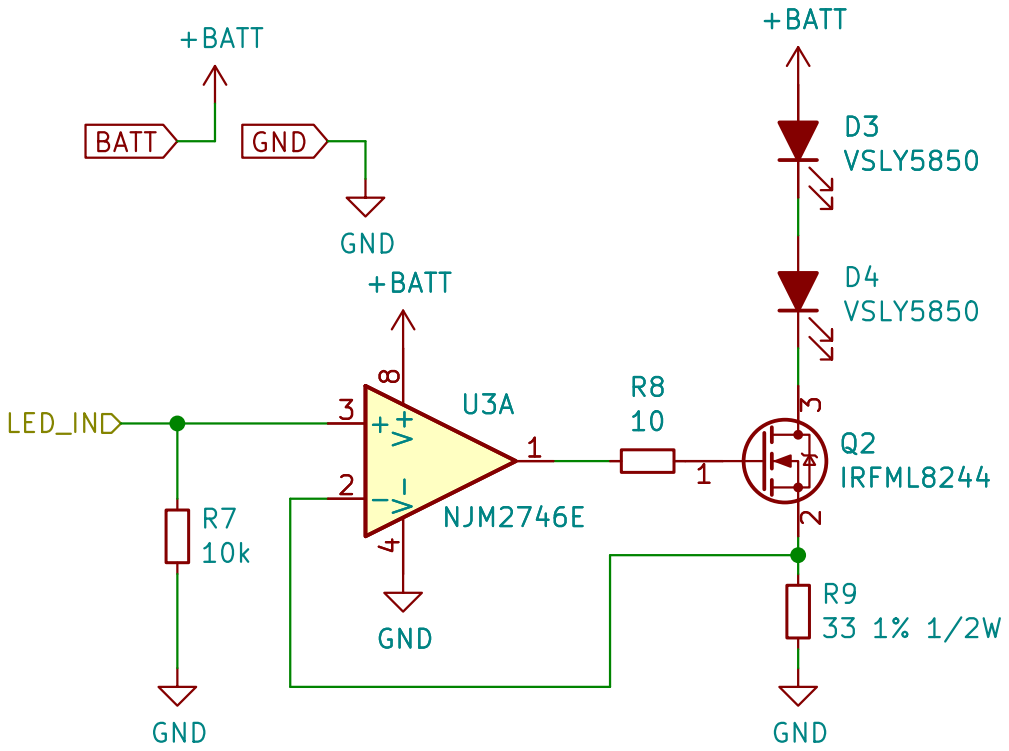
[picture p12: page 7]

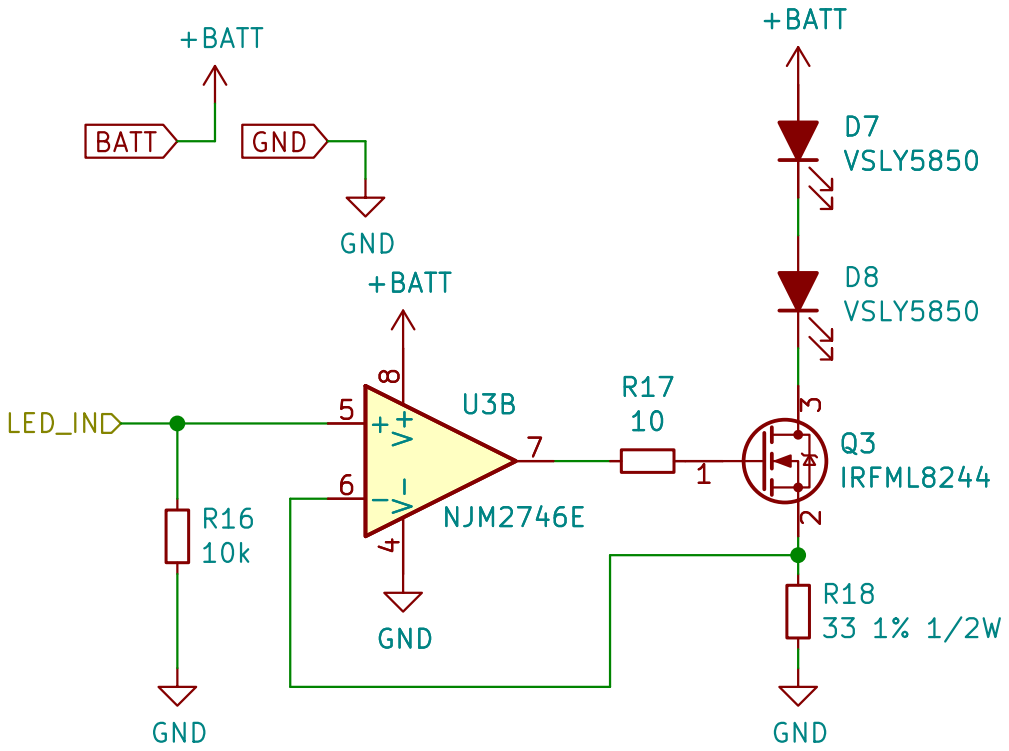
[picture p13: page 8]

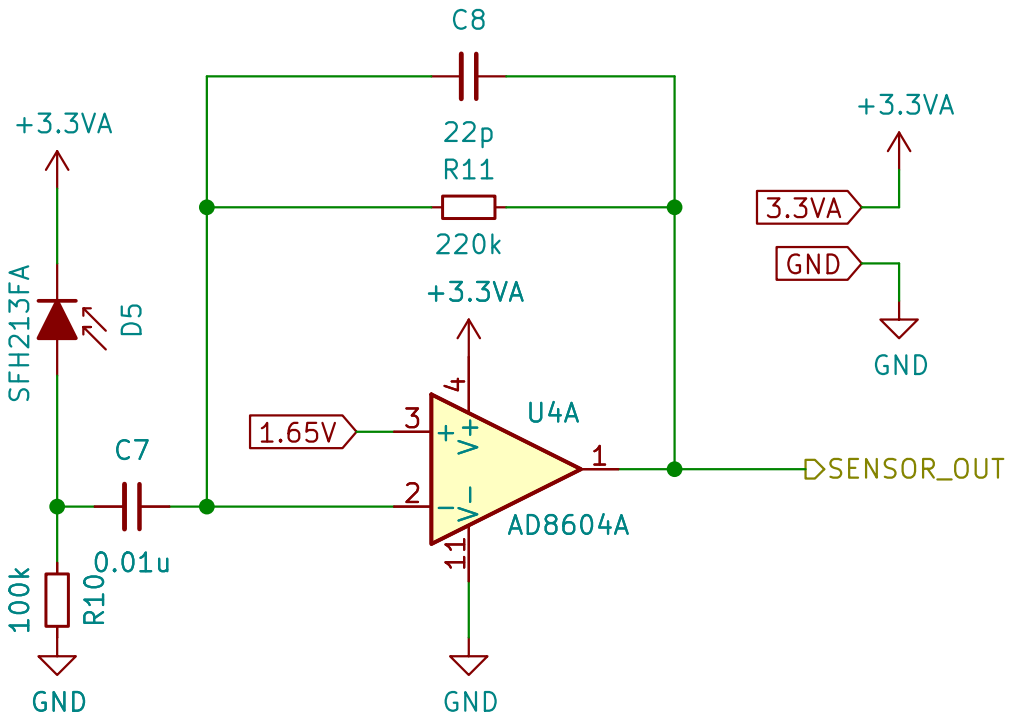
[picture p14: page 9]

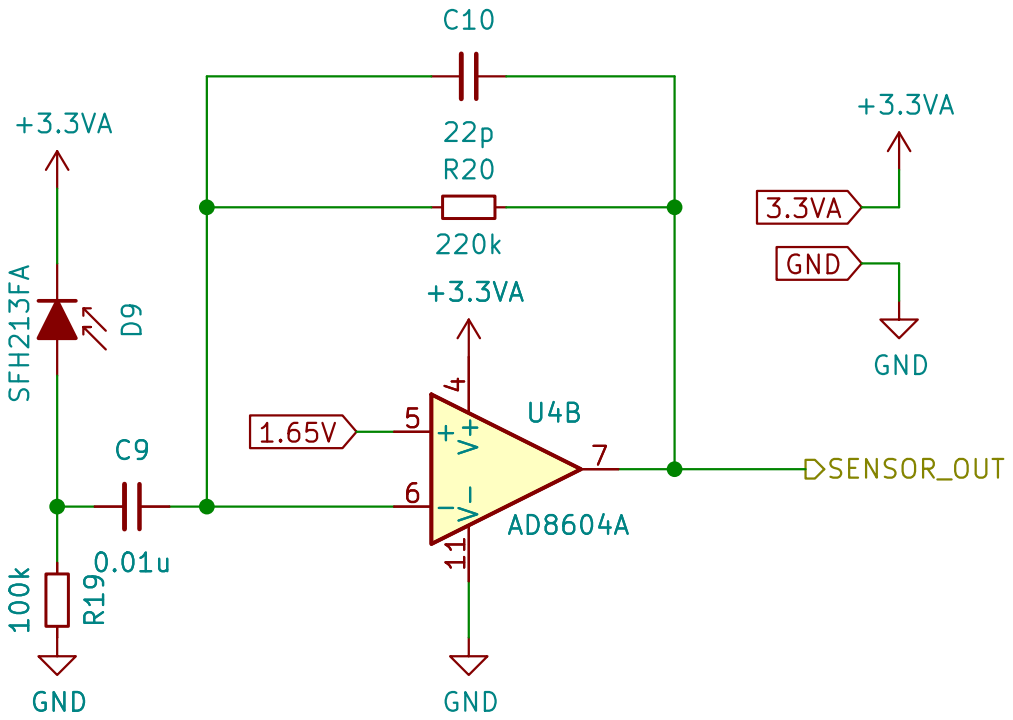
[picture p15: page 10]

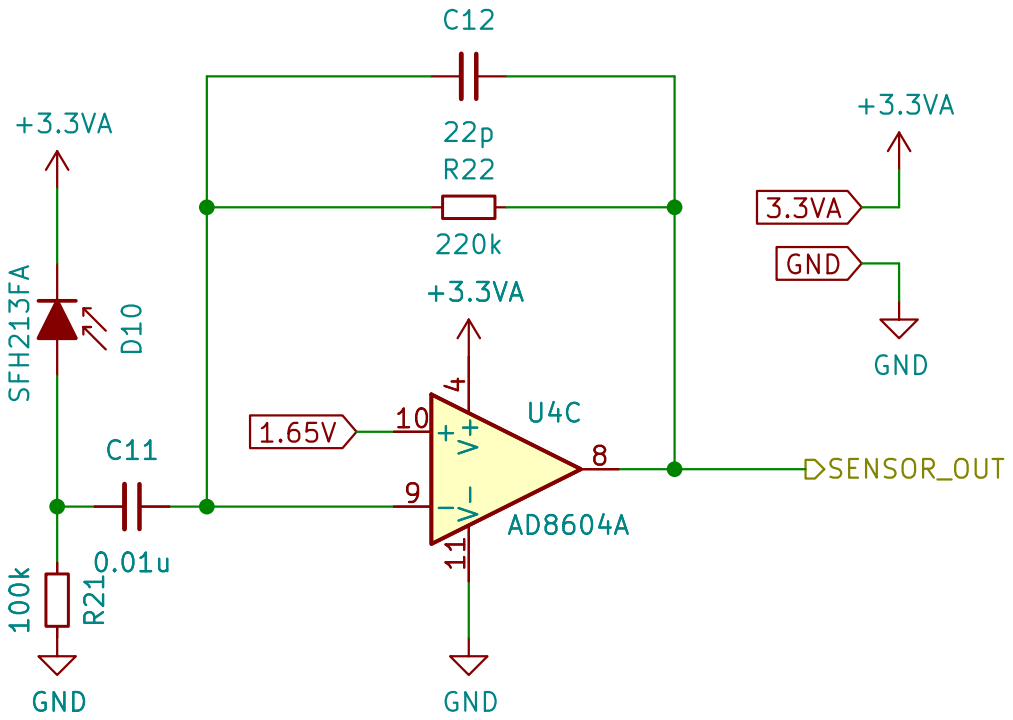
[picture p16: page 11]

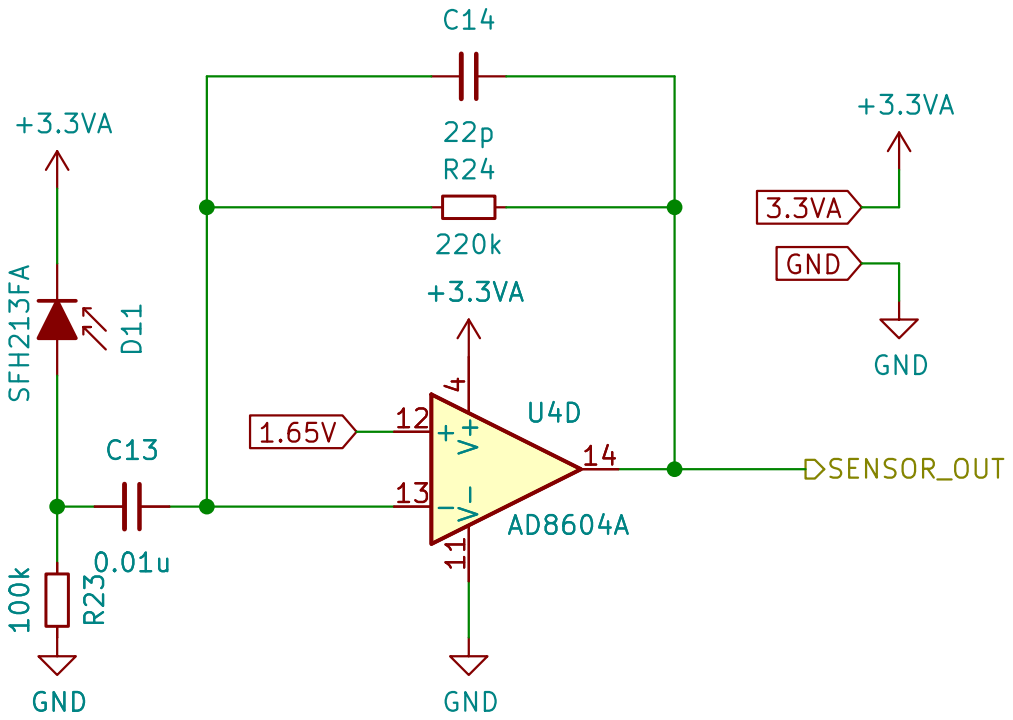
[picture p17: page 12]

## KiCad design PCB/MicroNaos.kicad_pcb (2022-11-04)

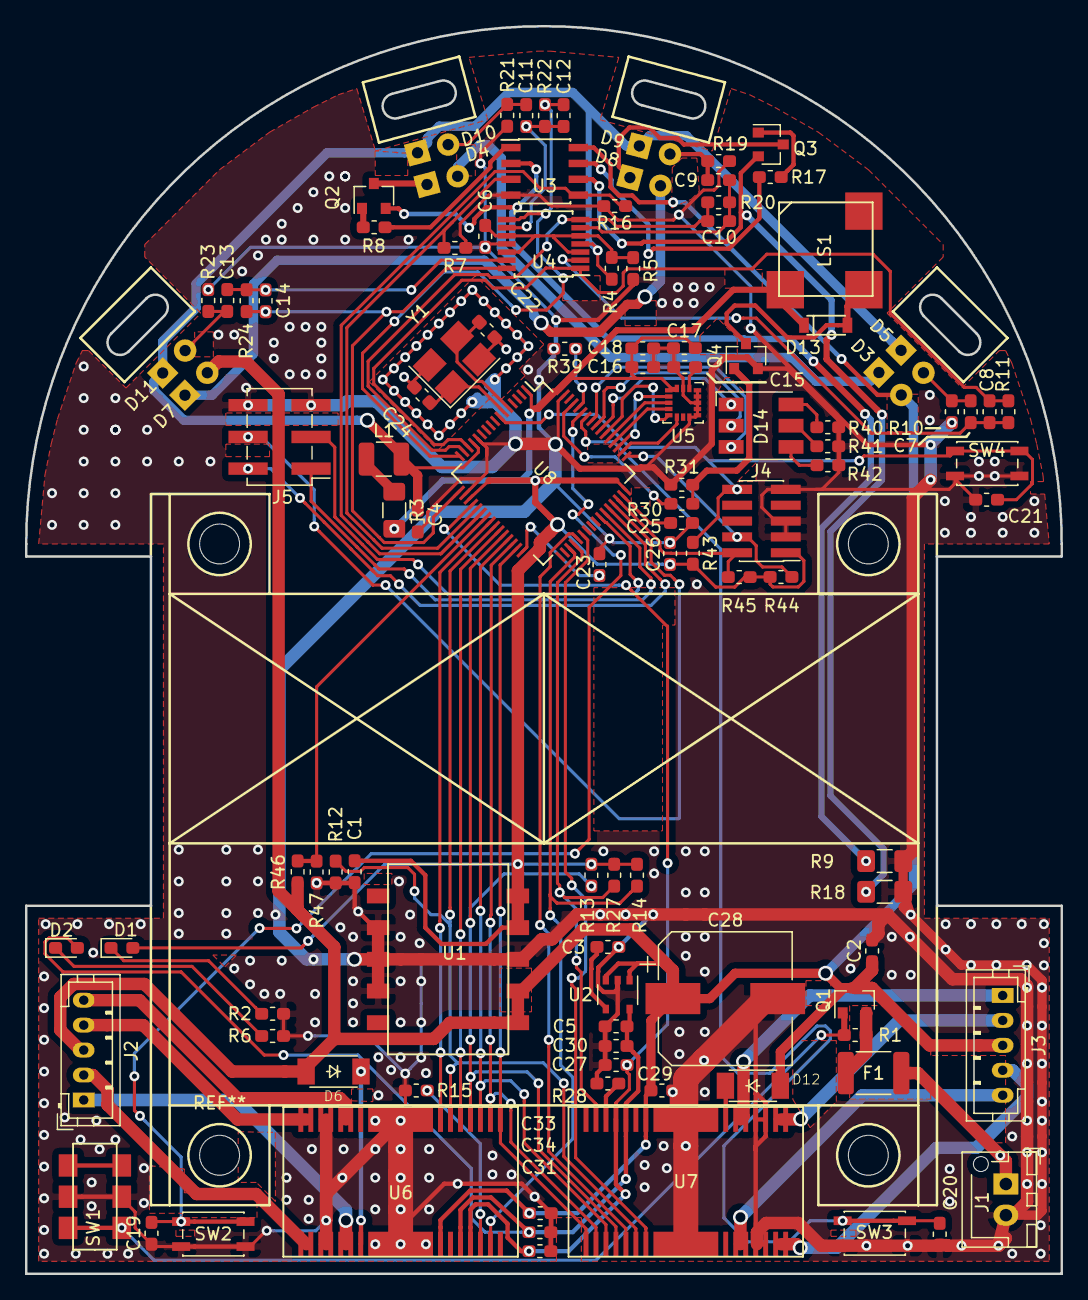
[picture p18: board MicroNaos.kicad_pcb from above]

Board: 2 copper layers, 83.0 x 100.0 mm, 109 parts (0 on the bottom side), 91 nets.

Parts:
C1: 3.3u; C_0603_1608Metric_Pad1.05x0.95mm_HandSolder
C2: 1u; C_0603_1608Metric_Pad1.05x0.95mm_HandSolder
C3, C7, C9, C11, C13, C16: 0.01u; C_0603_1608Metric_Pad1.05x0.95mm_HandSolder
C4, C5: 10u; C_0603_1608Metric_Pad1.05x0.95mm_HandSolder
C6, C15, C17, C19, C20, C21, C26: 0.1u; C_0603_1608Metric_Pad1.05x0.95mm_HandSolder
C8, C10, C12, C14: 22p; C_0603_1608Metric_Pad1.05x0.95mm_HandSolder
C18, C23, C25: 2.2u; C_0603_1608Metric_Pad1.05x0.95mm_HandSolder
C22, C24: 10p; C_0603_1608Metric_Pad1.05x0.95mm_HandSolder
C27, C29, C30, C31, C33, C34: 0.1uF; C_0603_1608Metric_Pad1.05x0.95mm_HandSolder
C28: 100uF; CP_Elec_10x10.5
D1: LED_3.3V; LED_0603_1608Metric_Pad1.05x0.95mm_HandSolder
D2: LED_5V; LED_0603_1608Metric_Pad1.05x0.95mm_HandSolder
D3, D4, D7, D8: VSLY5850; LED_D5.0mm_Sensor
D5, D9, D10, D11: SFH213FA; LED_D5.0mm_Sensor
D6, D12: 24V1W; SOD128
D13: GS1010FL; SOD-123FL
D14: OSTBABS4C2B; LED_RGB_5050-6
F1: SMD1812P150TF/24; Fuse_1812_4532Metric_Pad1.30x3.40mm_HandSolder
J1: BATTERY; JST_XH_B02B-XH-AM_1x02_P2.50mm_Vertical
J2, J3: PH_5Pin; JST_PH_B5B-PH-K_1x05_P2.00mm_Vertical
J4: Conn_ARM_JTAG_SWD_10; PinHeader_2x05_P1.27mm_Vertical_SMD
J5: Conn_02x03_Odd_Even; PinHeader_2x03_P2.54mm_Vertical_SMD
L1: 100u; L_1210_3225Metric
LS1: Speaker; UGCT7525AN4
Q1: IRLML6402; SOT-23
Q2, Q3, Q4: IRFML8244; SOT-23
R1, R10, R19, R21, R23: 100k; R_0603_1608Metric_Pad1.05x0.95mm_HandSolder
R2, R6: 1k; R_0603_1608Metric_Pad1.05x0.95mm_HandSolder
R3: 10; R_1206_3216Metric_Pad1.42x1.75mm_HandSolder
R4, R5: 1k 1%; R_0603_1608Metric_Pad1.05x0.95mm_HandSolder
R7, R12, R13, R14, R15, R16, R27, R28, R31, R39, R43, R44, R45, R47: 10k; R_0603_1608Metric_Pad1.05x0.95mm_HandSolder
R8, R17: 10; R_0603_1608Metric_Pad1.05x0.95mm_HandSolder
R9, R18: 33 1% 1/2W; R_1206_3216Metric_Pad1.42x1.75mm_HandSolder
R11, R20, R22, R24: 220k; R_0603_1608Metric_Pad1.05x0.95mm_HandSolder
R30: 100; R_0603_1608Metric_Pad1.05x0.95mm_HandSolder
R40, R41, R42: 330; R_0603_1608Metric_Pad1.05x0.95mm_HandSolder
R46: 33k; R_0603_1608Metric_Pad1.05x0.95mm_HandSolder
SW1: SSSS213202
SW2, SW3, SW4: SKRPACE010; SW_SPST_EVQP2
U1: M78SAR033-0.5
U2: TAR5SB50; TSOP-5_1.65x3.05mm_P0.95mm
U3: NJM2746E; SOIC-8_3.9x4.9mm_P1.27mm
U4: AD8604A; TSSOP-14_4.4x5mm_P0.65mm
U5: ICM-20602; LGA-16_3x3mm_P0.5mm_LayoutBorder3x5y
U6, U7: TB67S149FG; HSOP28-P-0450-0.80
U8: STM32F405RGTx; LQFP-64_10x10mm_P0.5mm
Y1: 12MHz; Crystal_SMD_SeikoEpson_FA238V-4Pin_3.2x2.5mm_HandSoldering

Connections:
1.65V: C6.1, R4.2, R5.1, U4.3 (+), U4.5 (+), U4.10 (+), U4.12 (+)
3.3V: C1.1, C16.1, C17.1, C18.1, C26.2, D1.2 (A), D13.1 (K), J4.1 (VTref), LS1.1, R3.2, R13.1, R14.1, R27.1, R43.1, R44.1, R45.1, U1.4 (Vout), U1.5 (Vout), U5.1 (VDDIO), U5.16 (VDD), U8.1 (VBAT), U8.19 (VDD), U8.32 (VDD), U8.48 (VDD), U8.64 (VDD)
3.3VA: C4.1, D5.1 (K), D9.1 (K), D10.1 (K), D11.1 (K), L1.2, R4.1, U4.4 (V+), U8.13 (VDDA)
5V: C5.1, C30.1, C34.1, D2.2 (A), U2.5 (Vout), U6.24 (VCC), U7.24 (VCC)
/Gyro/CS: U5.5 (~CS), U8.54 (PD2)
/Gyro/INT: U5.6 (INT), U8.50 (PA15)
/Gyro/SDI: U5.3 (SDA/SDI), U8.53 (PC12)
/Gyro/SDO: U5.4 (SAO/SD0), U8.52 (PC11)
/Gyro/SPC: U5.2 (SCL/SPC), U8.51 (PC10)
/IR_LED1/LED_IN: R7.2, U3.3 (+), U8.21 (PA5)
/IR_LED2/LED_IN: R16.2, U3.5 (+), U8.22 (PA6)
/IR_Sensor1/SENSOR_OUT: C8.1, R11.1, U4.1, U8.14 (PA0)
/IR_Sensor2/SENSOR_OUT: C10.1, R20.1, U4.7, U8.15 (PA1)
/IR_Sensor3/SENSOR_OUT: C12.1, R22.1, U4.8, U8.16 (PA2)
/IR_Sensor4/SENSOR_OUT: C14.1, R24.1, U4.14, U8.17 (PA3)
/Micon/BATT_CHECK: R46.2, R47.1, U8.23 (PA7)
/Micon/DAC: C27.1, C31.1, U6.25 (VREF), U7.25 (VREF), U8.20 (PA4)
/Micon/MOTOR1_CW: U6.7 (CW/CCW), U8.24 (PC4)
/Micon/MOTOR1_ERR: R14.2, U6.27 (ERR), U8.35 (PB14)
/Micon/MOTOR1_PWM: U6.5 (CLK), U8.26 (PB0)
/Micon/MOTOR2_CW: U7.7 (CW/CCW), U8.38 (PC7)
/Micon/MOTOR2_ERR: R27.2, U7.27 (ERR), U8.36 (PB15)
/Micon/MOTOR2_PWM: U7.5 (CLK), U8.37 (PC6)
/Micon/MOTOR_DMODE0: U6.1 (DMODE0), U7.1 (DMODE0), U8.30 (PB11)
/Micon/MOTOR_DMODE1: U6.2 (DMODE1), U7.2 (DMODE1), U8.29 (PB10)
/Micon/MOTOR_DMODE2: U6.3 (DMODE2), U7.3 (DMODE2), U8.28 (PB2)
/Micon/MOTOR_EN: R12.1, U6.6 (ENABLE), U7.6 (ENABLE), U8.25 (PC5)
/Micon/MOTOR_RESET: R13.2, U6.4 (RESET), U7.4 (RESET), U8.27 (PB1)
/Micon/NRST: C21.2, J4.10 (~RESET), R43.2, SW4.1, U8.7 (NRST)
/Micon/PB8_SPEAKER: R30.2, U8.61 (PB8)
/Micon/SWCLK: J4.4 (SWDCLK/TCK), R44.2, U8.49 (PA14)
/Micon/SWDIO: J4.2 (SWDIO/TMS), R45.2, U8.46 (PA13)
/Micon/SW_1: C20.2, SW3.1, U8.58 (PB6)
/Micon/SW_2: C19.2, SW2.1, U8.59 (PB7)
/Micon/UART_RX: J5.1, U8.43 (PA10)
/Micon/UART_TX: J5.3, U8.42 (PA9)
/Micon/USB_DM: J5.2, U8.44 (PA11)
/Micon/USB_DP: J5.4, U8.45 (PA12)
BATT: C2.1, C28.1, C29.1, C33.1, D3.2 (A), D6.2 (A), D7.2 (A), D12.2 (A), J2.3, J3.3, Q1.3 (D), R46.1, U1.1 (Vin), U1.2 (Vin), U2.1 (Vin), U2.3 (Control), U3.8 (V+), U6.22 (VM), U7.22 (VM)
GND: C1.2, C2.2, C3.2, C4.2, C5.2, C6.2, C15.2, C16.2, C17.2, C18.2, C19.1, C20.1, C21.1, C22.2, C23.1, C24.2, C25.1, C26.1, C27.2, C28.2, C29.2, C30.2, C31.2, C33.2, C34.2, J1.2, J4.3 (GND), J4.5 (GND), J4.9 (GNDDetect), J5.5, J5.6, Q4.2 (S), R2.2, R5.2, R6.2, R7.1, R9.2, R10.1, R12.2, R15.2, R16.1, R18.2, R19.1, R21.1, R23.1, R28.2, R31.1, R39.2, R40.1, R41.1, R42.1, R47.2, SW1.2 (B), SW2.2, SW3.2, SW4.2, U1.3 (GND), U1.7 (GND), U1.8 (GND), U1.9 (GND), U2.2 (GND), U3.4 (V-), U4.11 (V-), U5.8 (FSYNC), U5.9 (GND), U5.10 (GND), U5.11 (GND), U5.12 (GND), U5.13 (GND), U5.15 (GND), U6.11 (RSGNDA), U6.12 (RSGNDA), U6.17 (RSGNDB), U6.18 (RSGNDB), U6.FIN1 (GND), U6.FIN2 (GND), U7.11 (RSGNDA), U7.12 (RSGNDA), U7.17 (RSGNDB), U7.18 (RSGNDB), U7.FIN1 (GND), U7.FIN2 (GND), U8.12 (VSSA), U8.18 (VSS), U8.63 (VSS), Y1.2, Y1.4
unnamed: C3.1, U2.4 (Noise)
unnamed: C7.1, C8.2, R11.2, U4.2 (-)
unnamed: C7.2, D5.2 (A), R10.2
unnamed: C9.2, D9.2 (A), R19.2
unnamed: C9.1, C10.2, R20.2, U4.6 (-)
unnamed: C11.1, C12.2, R22.2, U4.9 (-)
unnamed: C11.2, D10.2 (A), R21.2
unnamed: C13.1, C14.2, R24.2, U4.13 (-)
unnamed: C13.2, D11.2 (A), R23.2
unnamed: C15.1, U5.14 (REGOUT)
unnamed: C22.1, U8.5 (PH0), Y1.3
unnamed: C23.2, U8.31 (VCAP_1)
unnamed: C24.1, U8.6 (PH1), Y1.1
unnamed: C25.2, U8.47 (VCAP_2)
unnamed: D1.1 (K), R2.1
unnamed: D2.1 (K), R6.1
unnamed: D3.1 (K), D4.2 (A)
unnamed: D4.1 (K), Q2.3 (D)
unnamed: D6.1 (K), U6.21 (VCOM)
unnamed: D7.1 (K), D8.2 (A)
unnamed: D8.1 (K), Q3.3 (D)
unnamed: D12.1 (K), U7.21 (VCOM)
unnamed: D13.2 (A), LS1.2, Q4.3 (D)
unnamed: D14.1 (BA), U8.55 (PB3)
unnamed: D14.2 (GA), U8.56 (PB4)
unnamed: D14.3 (RA), U8.57 (PB5)
unnamed: D14.4 (RK), R42.2
unnamed: D14.5 (GK), R41.2
unnamed: D14.6 (BK), R40.2
unnamed: F1.1, Q1.2 (S), R1.1
unnamed: F1.2, J1.1
unnamed: J2.1, U6.19 (OUTB+), U6.20 (OUTB+)
unnamed: J2.2, U6.16 (OUTB-)
unnamed: J2.4, U6.13 (OUTA-)
unnamed: J2.5, U6.9 (OUTA+), U6.10 (OUTA+)
unnamed: J3.1, U7.19 (OUTB+), U7.20 (OUTB+)
unnamed: J3.2, U7.16 (OUTB-)
unnamed: J3.4, U7.13 (OUTA-)
unnamed: J3.5, U7.9 (OUTA+), U7.10 (OUTA+)
unnamed: L1.1, R3.1
unnamed: Q1.1 (G), R1.2, SW1.1 (A)
unnamed: Q2.1 (G), R8.1
unnamed: Q2.2 (S), R9.1, U3.2 (-)
unnamed: Q3.1 (G), R17.1
unnamed: Q3.2 (S), R18.1, U3.6 (-)
unnamed: Q4.1 (G), R30.1, R31.2
unnamed: R8.2, U3.1
unnamed: R15.1, U6.26 (OSCM)
unnamed: R17.2, U3.7
unnamed: R28.1, U7.26 (OSCM)
unnamed: R39.1, U8.60 (BOOT0)

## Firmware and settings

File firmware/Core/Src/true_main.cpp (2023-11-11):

#include "main.h"
#include "usb_device.h"
#include "usbd_hid.h"

#include "true_main.hpp"
#include "led.hpp"
#include "spi.hpp"
#include "motor.hpp"
#include "ir_led.hpp"
#include "ir_sensor.hpp"
#include "maze.hpp"
#include "tools.hpp"
#include "flash.hpp"

#include "SEGGER_RTT.h"
#include "arm_math.h"
#include "mazelibrary.hpp"

#include <stdio.h>


extern ADC_HandleTypeDef hadc2;

extern TIM_HandleTypeDef htim6;
extern TIM_HandleTypeDef htim7;
extern TIM_HandleTypeDef htim11;


//各壁センサのインスタンスを作成
namespace ir{
	static Ir_sensor side_right(0, 350);
	static Ir_sensor front_right(1, 300);
	static Ir_sensor front_left(2, 300);
	static Ir_sensor side_left(3, 350);
}

//ジャイロセンサのインスタンスを作成
static spi::Gyro gyro;

static Motor motor;
namespace sw{
	static volatile uint8_t l = 0;
	static volatile uint8_t r = 0;
}

static volatile float32_t gyro_z_e_i = 0.0f;

static std::vector<std::vector<uint8_t>> start_coord = {{0, 0}};
// static std::vector<std::vector<uint8_t>> goal_coord = {{1, 0}, {1, 1}, {2, 0}, {2, 1}};
static std::vector<std::vector<uint8_t>> goal_coord = {{7, 7}, {7, 8}, {8, 7}, {8, 8}};
// static std::vector<std::vector<uint8_t>> goal_coord = {{8, 3}};

static Maze maze(start_coord, goal_coord);
static Mouse mouse;
static AdachiMethod method(&maze, &mouse);

static Flash flash;

static uint8_t usbmouse_enable = 0;

struct USBMouse {
	uint8_t button;
	int8_t x;
	int8_t y;
	int8_t w;
};

static struct USBMouse usbmouse;

extern USBD_HandleTypeDef hUsbDeviceFS;

void failsafe(void){
	motor.stop();
	motor.enable(0);
	__disable_irq();
	while(1){
		led::set(1, 0, 0);
		HAL_Delay(500);
		led::set(0, 0, 0);
		HAL_Delay(500);
	}
}

void HAL_TIM_PeriodElapsedCallback(TIM_HandleTypeDef *htim){
	
	//TIM6オーバーフロー割り込みは160kHz周期で呼び出される
	//呼び出されたときにデータを格納する。
	if(htim->Instance == htim6.Instance){
		ir::front_right.update_data();
		ir::side_right.update_data();
		ir::front_left.update_data();
		ir::side_left.update_data();
	}

	//TIM7オーバーフロー割り込みは1kHz周期で呼び出される
	if(htim->Instance == htim7.Instance){
		if (gyro.calibration_status == 0){
			gyro.calibration_gyro_z();
		}else{
			gyro.update_z_angle();
		}
		
		/* //宴会芸用のプログラム
		if(gyro.calibration_status == 1){
			float32_t temp_deg_speed;
			const float32_t Kp = 10.0f;
			const float32_t Ki = 0.01f;
			const float32_t Kd = 1.0f;
			
			float32_t gyro_z_e = gyro.z_angle;
			
			//数値積分
			gyro_z_e_i += gyro.z_angle;
			if(gyro_z_e_i > 10.0f) gyro_z_e_i = 10.0f;
			if(gyro_z_e_i < -10.0f) gyro_z_e_i = -10.0f;

			//数値微分
			float32_t gyro_z_e_d = gyro.z_angle - gyro.z_angle_previous;

			temp_deg_speed = -1 * (Kp * gyro_z_e + Ki * gyro_z_e_i + Kd * gyro_z_e_d);
			motor.set_target_deg(temp_deg_speed);
		}
		*/

		/*
		 * motor.state.forwardではmotor.state.deltamax分だけ直進する。
		 * 
		 */

		if(motor.state.mode == motor.state.forward){
			// モード変更時はdeltaをリセットしておく。
			if(motor.state.mode_previous != motor.state.forward){
				motor.state.delta = 0.0f;
				motor.state.mode_lock = 1;

				float32_t target_speed_l, target_speed_r;

				//速度ターゲットを直進スピードに設定する。(符号も合わせる)
				if(motor.state.delta_max > 0){
					target_speed_l = motor.forward_speed;
				}else{	
					target_speed_l = -1.0f * motor.forward_speed;	
				}

				target_speed_r = target_speed_l;

				
				//拘束条件として右と左のスピードは同じになる。
				motor.set_target(target_speed_l, target_speed_r);
				motor.state.mode_previous = motor.state.forward;
			}else{
				motor.state.delta += (motor.speedstate_l.current + motor.speedstate_r.current) / 2.0f * motor.t_scale;
				
				

				if(motor.state.slow_down == 1){
					//減速を行う場合(デフォルト)
					if(abs(motor.state.delta_max - motor.state.delta) 
						< motor.forward_speed * (motor.forward_speed / motor.accel) / 2.0f){
					
						//速度ターゲットを0に設定する
						//拘束条件として右と左のスピードは同じになる。
						motor.set_target(0.0f, 0.0f);
					}
					if(abs(motor.speedstate_l.current) < (motor.accel * motor.t_scale)){
						motor.state.mode = motor.state.stop;
						motor.state.mode_previous = motor.state.stop;
						motor.state.mode_lock = 0;
					}
				}else{
					float32_t target_speed_l, target_speed_r;

					//速度ターゲットを直進スピードに設定する。(符号も合わせる)
					if(motor.state.delta_max > 0){
						target_speed_l = motor.forward_speed;
					}else{	
						target_speed_l = -1.0f * motor.forward_speed;	
					}

					target_speed_r = target_speed_l;
					if(ir::side_left.intensity > 800){
						float32_t diff = static_cast<float32_t>(ir::side_left.intensity - 800);
						target_speed_r += diff * 0.1f;
					}else if(ir::side_right.intensity > 800){
						float32_t diff = static_cast<float32_t>(ir::side_right.intensity - 800);
						target_speed_l += diff * 0.1f;

					}
					motor.set_target(target_speed_l, target_speed_r);
					if(abs(motor.state.delta_max - motor.state.delta) < (motor.forward_speed * motor.t_scale)){
						//形式的にstopにしておく(あまり直観的ではない)
						motor.state.mode = motor.state.stop;
						motor.state.mode_previous = motor.state.stop;
						motor.state.mode_lock = 0;
					}
				}
			}
		}else if(motor.state.mode == motor.state.turn){
			// モード変更時はdeltaをリセットしておく。
			if(motor.state.mode_previous != motor.state.turn){
				motor.state.deg_std = gyro.z_angle;
				gyro_z_e_i = 0.0f;
				motor.state.delta_deg = 0.0f;
				motor.state.mode_lock = 1;

				float32_t target_speed_deg;

				//速度ターゲットを直進スピードに設定する。(符号も合わせる)
				if(motor.state.delta_max_deg > 0){
					target_speed_deg = motor.turn_speed;
				}else{	
					target_speed_deg = -1.0f * motor.turn_speed;	
				}
				//回転方向の速度を設定
				motor.set_target_deg(target_speed_deg);
				motor.state.mode_previous = motor.state.turn;
			}else{
				//差分を取得
				motor.state.delta_deg = motor.state.delta_max_deg - (gyro.z_angle - motor.state.deg_std);

				float32_t temp_deg_speed;
				/*
				const float32_t Kp = 10.0f;
				const float32_t Ki = 0.01f;
				const float32_t Kd = 1.0f;
				*/
				
				const float32_t Kp = 8.0f;
				const float32_t Ki = 0.05f;
				const float32_t Kd = 2.0f;

				float32_t gyro_z_e = motor.state.delta_deg;
				
				//数値積分
				gyro_z_e_i += gyro_z_e;
				if(gyro_z_e_i > 10.0f) gyro_z_e_i = 10.0f;
				if(gyro_z_e_i < -10.0f) gyro_z_e_i = -10.0f;

				//数値微分
				float32_t gyro_z_e_d = gyro.z_angle - gyro.z_angle_previous;

				temp_deg_speed = Kp * gyro_z_e + Ki * gyro_z_e_i + Kd * gyro_z_e_d;
				
				if(temp_deg_speed > motor.turn_speed) temp_deg_speed = motor.turn_speed;
				if(temp_deg_speed < -1 * motor.turn_speed) temp_deg_speed = -1 * motor.turn_speed;

				motor.set_target_deg(temp_deg_speed);

				if(abs(motor.state.delta_deg) < 0.1f){
					motor.set_target_deg(0.0f);
					motor.state.mode = motor.state.stop;
					motor.state.mode_previous = motor.state.stop;
					motor.state.mode_lock = 0;
				}

			}
		}
		
		motor.update_speed();
		
	}
	//TIM7オーバーフロー割り込みは100Hz周期で呼び出される
	if(htim->Instance == htim11.Instance){
		if(motor.speedstate_l.target > 500 || motor.speedstate_r.target > 500){
			failsafe();
		}
		//スイッチの状態を確認
		if (HAL_GPIO_ReadPin(SW_1_GPIO_Port, SW_1_Pin) == GPIO_PIN_RESET){
			sw::r = 1;
		}else{
			sw::r = 0;
		}if (HAL_GPIO_ReadPin(SW_2_GPIO_Port, SW_2_Pin) == GPIO_PIN_RESET){
			sw::l = 1;
		}else{
			sw::l = 0;
		}
		if(usbmouse_enable == 1){

			usbmouse.button = 0;
			usbmouse.x = 0;
			usbmouse.y = 0;

			if (sw::r == 1) usbmouse.button = usbmouse.button | 0b00000010;
			if (sw::l == 1) usbmouse.button = usbmouse.button | 0b00000001;

			usbmouse.x = -1 * (gyro.read_accel_x() / 16) / 5;
			usbmouse.y = -1 * (gyro.read_accel_y() / 16) / 5;
			
			USBD_HID_SendReport(&hUsbDeviceFS, (uint8_t *) &usbmouse, sizeof(struct USBMouse));
			SEGGER_RTT_printf(0, "%d, %d, %d, %d\n", ir::side_left.intensity, ir::front_left.intensity, ir::front_right.intensity, ir::side_right.intensity);	
		}

		//バッテリーの状態を確認
		HAL_ADC_Start(&hadc2);
		if(HAL_ADC_PollForConversion(&hadc2, 10) == HAL_OK){
			//約10.5V(3260)を下回った場合は警告する<-11.5Vで引っかかったので3100に変更
			if(HAL_ADC_GetValue(&hadc2) < 3000){
				failsafe();
			}
		}
		HAL_ADC_Stop(&hadc2);
			
		// 角度を送信
		//char s[8];
		//snprintf(s, sizeof(s), "%f", gyro.z_angle);
		//SEGGER_RTT_printf(0, "gyro_z = %s\n", s);	
		/*
		SEGGER_RTT_printf(0, "\n");
		SEGGER_RTT_printf(0, "+%d+\n", maze.node[0][1].wall.up);
		SEGGER_RTT_printf(0, "%d %d\n", maze.node[0][1].wall.left, maze.node[0][1].wall.right);
		SEGGER_RTT_printf(0, "+%d+\n", maze.node[0][0].wall.up);
		SEGGER_RTT_printf(0, "%d %d\n", maze.node[0][0].wall.left, maze.node[0][0].wall.right);
		SEGGER_RTT_printf(0, "+%d+\n", maze.node[0][0].wall.down);
		*/
	}
}

extern DAC_HandleTypeDef hdac;

/**
 * @brief 真のmain関数
 * 
 */
void true_main(void){
	HAL_Delay(100);
	//各部分の初期化
    SEGGER_RTT_Init();
	led::init();
	ir_led::init();
	motor.init();
	gyro.init();
	
	//Who_am_iを読みジャイロをチェックする。(RTTに出力)
	gyro.who_am_i();
	
	ir_led::set_state(1,1);
	Ir_sensor::init();


	//割り込み用のTIMを起動
	HAL_TIM_Base_Start_IT(&htim6);
	HAL_TIM_Base_Start_IT(&htim7);
	HAL_TIM_Base_Start_IT(&htim11);

	uint8_t mode = 0;
	uint16_t start_count = 0;
	if(sw::r == 1){
		led::set(0, 0, 1);

		flash.erase();
		
		usbmouse.button = 0;
		
		usbmouse.x = 0;
		usbmouse.y = 0;
		usbmouse.w = 0;
		usbmouse_enable = 1;

		motor.enable(0);

		while(1){

		}
	}
	while(1){
		
		//前センサを適度に塞ぐと起動する
		while (1){
			if(sw::l == 1){
				if(mode == 0){
					mode = 1;
					led::set(0, 1, 1);
				}else if(mode == 1){
					mode = 2;
					led::set(1, 0, 1);
				}else{
					mode = 0;
					led::set(0, 0, 0);
				}
				HAL_Delay(200);
			}
			if(ir::front_right.intensity > 1000){
				start_count++;
			}else{
				if(start_count > 0) start_count--;
			}
			if(start_count > 500) break;
			HAL_Delay(1);
		}
		
		//動作開始	
		led::set(0, 1, 0);
		
		gyro.calibration_status = 0;
		while(gyro.calibration_status == 0);
		gyro.z_angle = 0.0f;
		
		HAL_Delay(2000);
		led::set(0, 0, 0);
		if (mode == 0){
			for (int i = 0; i < 16; i++){
				for (int j = 0; j < 16; j++){
					maze.wall[i][j] = 0;
				}
			}
		}else{
			flash.load();
			if(flash.is_elased == 0){
				for (int i = 0; i < 16; i++){
					for (int j = 0; j < 16; j++){
						maze.wall[i][j] = flash.wall[i][j];
					}
				}
			}
		}
		
		mouse.x = 0;
		mouse.y = 0;
		mouse.direction = Direction::up;

		/*デバッグ向け直進処理*/
		/*		
		motor.forward(810, 0);
		motor.forward(90, 1);
		while(1){}
		*/
		
		/*デバッグ向け回転処理*/
		/*
		for (uint8_t i = 0; i < 4; i++){
			motor.turn(90.0f);
			HAL_Delay(10);
		}
		while(1){}
		*/
		/*---スタート時の処理---*/
		
		//1回目の壁当ては左壁でやるので右を向く
		motor.kabeate1();
		mouse.direction = Direction::right;
		
		if(ir::front_left.intensity > 1000 && ir::front_right.intensity > 1000){
			uint8_t temp_wall = Direction::up;
			temp_wall = tools::get_rotated_wall(mouse.direction, temp_wall);
			maze.wall_update(mouse.x, mouse.y, temp_wall);
		}
		
		//2回目の壁当ては下壁でやるので上を向く
		motor.kabeate2();
		mouse.direction = Direction::up;
		if(ir::front_left.intensity > 1000 && ir::front_right.intensity > 1000){
			uint8_t temp_wall = Direction::up;
			temp_wall = tools::get_rotated_wall(mouse.direction, temp_wall);
			maze.wall_update(mouse.x, mouse.y, temp_wall);
		}

		
		gyro.z_angle = 0.0f;

		motor.forward(90.0f, 0);
		mouse.y = 1;
		
		/*---スタート時の処理終了。(0,1からスタート)---*/
		//実際は(0,0.5)あたりにいる。

		for(uint8_t step = 0; step < 4; step++){
			if(mode != 0){
				step = 3;
			}
        	if(step != 2){
        	    method.set_goals(maze.goal);
        	}else if (step == 2){
            	method.set_goals(maze.start);
        	}
			switch(step){
				case 1:
					led::set(1, 1, 0);
					break;
				case 2:
					led::set(1, 0, 1);
					break;
				case 3:
					led::set(0, 1, 1);
					break;
			}
			
			if(step == 3){
				//最短走行の時に速度を決定する。
				switch(mode){
					case 0:
						motor.forward_scale = 1.25f;
						break;
					case 1:
						motor.forward_scale = 1.0f;
						break;
					case 2:
						motor.forward_scale = 1.25f;
						break;
				}
			}else{
				motor.forward_scale = 1.0f;
			}

			while(1){	
			//迷路からの壁情報の読み込み
				uint8_t temp_wall = 0;
				if(ir::front_left.wall_detect() && ir::front_right.wall_detect()){
					temp_wall += Direction::up;
				}
				if(ir::side_left.wall_detect()){
					temp_wall += Direction::left;
				}
				if(ir::side_right.wall_detect()){
					temp_wall += Direction::right;
				}

				/*ジャイロでの補正*/
				/*
				float32_t gyro_turn_deg = -1 * (gyro.z_angle 
					- static_cast<float32_t>(tools::direction_to_deg(mouse.direction)));
				motor.turn(tools::deg_normalize(gyro_turn_deg));
				*/

				uint8_t rotated_wall = tools::get_rotated_wall(mouse.direction, temp_wall);
				
				maze.wall_update(mouse.x, mouse.y, rotated_wall);
				std::vector<uint8_t> now{mouse.x, mouse.y};
				method.set_start(now);


				/*
				else if(step == 2){
					led::set(1, 0, 1);
					method.set_goals(method.get_unknown_in_shortest());
					if(method.goals.empty()) break;

				}
				*/

				if(step == 3){
					method.set_wall_at_unknown();
				}
				
				//コストの再計算
				method.cost_refresh();
				//いらない経路の削除
				method.delete_bad_route();

				if(step == 1){
					motor.forward(90.0f);
					if((rotated_wall & Direction::up) != Direction::up){
						//上に壁がない場合回転しない						

					}else if((rotated_wall & Direction::left) != Direction::left){
						//そのうえで左に壁がない場合左に進む
						mouse.turn_inv90();
						motor.turn(-90.0f);
						
					}else if((rotated_wall & Direction::right) != Direction::right){
						//そのうえで右に壁がない場合右に進む
						mouse.turn_90();
						motor.turn(90.0f);
					}else{
						mouse.turn_180();
						motor.kabeate_turn_r();
						gyro.z_angle = static_cast<float32_t>(tools::direction_to_deg(mouse.direction));
					}
					motor.forward(90.0f);
					mouse.move_forward();
					flash.save(maze.wall);
					led::set(0, 0, 1);
					HAL_Delay(500);
					break;
					
				}
				
				if(step == 0 && method.goal_check()){
					break;
				}
				if(step == 3 && method.goal_check()){
					motor.forward(90.0f);
					while(1){
						led::set(1, 1, 1);
						HAL_Delay(500);
						led::set(0, 0, 0);
						HAL_Delay(500);
					}
				}
				
				int16_t mouse_deg = tools::direction_to_deg(mouse.direction);
				int16_t maze_deg = tools::direction_to_deg(maze.route[mouse.x][mouse.y]);

				int16_t turn_deg = tools::deg_sub(mouse_deg, maze_deg);
				
				if(step == 2 && method.goal_check()){
					motor.forward(90.0f);
					turn_deg = tools::deg_sub(mouse_deg, tools::direction_to_deg(Direction::up));
					switch(turn_deg){
						case 0:
							break;
						case 90:
							mouse.turn_inv90();
							motor.turn(-90.0f);
							break;
						case -90:
							mouse.turn_90();
							motor.turn(90.0f);
							break;
						case 180:
							mouse.turn_180();
							motor.turn(180.0f);
							break;
					}

					motor.kabeate1();
					motor.kabeate2();
					
					flash.save(maze.wall);
					led::set(0, 0, 1);
					HAL_Delay(500);

					led::set(1, 0, 1);
					HAL_Delay(2000);
					
					gyro.z_angle = static_cast<float32_t>(tools::direction_to_deg(mouse.direction));

					motor.forward(90.0f, 0);
					mouse.y = 1;
					break;
				}

				if(step < 3){
					
					const uint16_t side_wall_near = 1200;
					float32_t current_ideal_angle = static_cast<float32_t>(tools::direction_to_deg(mouse.direction));
					switch(turn_deg){
						case 0:

							if(ir::side_left.intensity > side_wall_near){
								motor.forward(90.0f);
								motor.turn(90.0f);
								motor.kabeate0();
								motor.turn(-90.0f);
								motor.forward(90.0f, 0);

							}else if(ir::side_right.intensity > side_wall_near){
								motor.forward(90.0f);
								motor.turn(-90.0f);
								motor.kabeate0();
								motor.turn(90.0f);
								motor.forward(90.0f, 0);

							}else{
								const float32_t forward_gain = 0.98;
								motor.forward(180.0f * forward_gain, 0);
							}
							break;

						case 90:
							mouse.turn_inv90();
							motor.forward(90.0f);

							if(abs(tools::deg_sub(gyro.z_angle, current_ideal_angle)) < 5.0f ){
								//5°以上ずれている場合は壁当てする。
								motor.turn(-90.0f);
							}else{
								if(temp_wall == (Direction::left + Direction::up)){
									motor.turn(180.0f);
									motor.kabeate0();
									motor.turn(90.0f);
									motor.kabeate0();
									gyro.z_angle = current_ideal_angle;
								}else if(temp_wall == (Direction::up)){
									motor.turn(180.0f);
									motor.kabeate0();
									motor.turn(90.0f);
									gyro.z_angle = current_ideal_angle;
								}else if(temp_wall == (Direction::left)){
									motor.turn(-90.0f);
									motor.kabeate0();
									gyro.z_angle = current_ideal_angle;
								}

							}
							
							motor.forward(90.0f, 0);
							break;

						case -90:
							mouse.turn_90();
							motor.forward(90.0f);

							if(abs(tools::deg_sub(gyro.z_angle, current_ideal_angle)) < 5.0f ){
								//5°以上ずれている場合は壁当てする。
								motor.turn(90.0f);
							}else{
								if(temp_wall == (Direction::right + Direction::up)){
									motor.turn(180.0f);
									motor.kabeate0();
									motor.turn(-90.0f);
									motor.kabeate0();
									gyro.z_angle = current_ideal_angle;
								}else if(temp_wall == (Direction::up)){
									motor.turn(180.0f);
									motor.kabeate0();
									motor.turn(-90.0f);
									gyro.z_angle = current_ideal_angle;
								}else if(temp_wall == (Direction::right)){
									motor.turn(90.0f);
									motor.kabeate0();
									gyro.z_angle = current_ideal_angle;
								}
							}

							motor.forward(90.0f, 0);
							break;

						case 180:
							mouse.turn_180();
							motor.forward(90.0f);
							
							if(temp_wall == (Direction::left + Direction::right + Direction::up)
							|| temp_wall == (Direction::right + Direction::up)){
								motor.kabeate_turn_r();
								gyro.z_angle = static_cast<float32_t>(tools::direction_to_deg(mouse.direction));
							}else if(temp_wall == (Direction::left + Direction::up)){
								motor.kabeate_turn_l();
								gyro.z_angle = static_cast<float32_t>(tools::direction_to_deg(mouse.direction));
							}else if(temp_wall == Direction::left){
								motor.turn(-90.0f);
								motor.kabeate0();
								motor.turn(-90.0f);
							}else if(temp_wall == Direction::right){
								motor.turn(90.0f);
								motor.kabeate0();
								motor.turn(90.0f);
							}else{
								motor.turn(180.0f);
							}

							motor.forward(90.0f, 0);
							break;
					}
				}else{
					switch(turn_deg){
						case 0:
							motor.forward(180.0f, 0);
							break;
						case 90:
							mouse.turn_inv90();
							motor.forward(90.0f);
							motor.turn(-90.0f);
							motor.forward(90.0f, 0);
							break;
						case -90:
							mouse.turn_90();
							motor.forward(90.0f);
							motor.turn(90.0f);
							motor.forward(90.0f, 0);
							break;
						case 180:
							mouse.turn_180();
							motor.turn(180.0f);
							motor.forward(90.0f, 0);
							break;
					}
				}

				mouse.move_forward();
			}
		} 
	}

}

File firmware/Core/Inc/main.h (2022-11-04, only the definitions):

#define DAC_Pin GPIO_PIN_4
#define DAC_GPIO_Port GPIOA
#define IR_LED1_Pin GPIO_PIN_5
#define IR_LED1_GPIO_Port GPIOA
#define IR_LED2_Pin GPIO_PIN_6
#define IR_LED2_GPIO_Port GPIOA
#define BATT_CHECK_Pin GPIO_PIN_7
#define BATT_CHECK_GPIO_Port GPIOA
#define MOTOR1_CW_Pin GPIO_PIN_4
#define MOTOR1_CW_GPIO_Port GPIOC
#define MOTOR_EN_Pin GPIO_PIN_5
#define MOTOR_EN_GPIO_Port GPIOC
#define MOTOR1_PWM_Pin GPIO_PIN_0
#define MOTOR1_PWM_GPIO_Port GPIOB
#define MOTOR_RESET_Pin GPIO_PIN_1
#define MOTOR_RESET_GPIO_Port GPIOB
#define MOTOR_DMODE2_Pin GPIO_PIN_2
#define MOTOR_DMODE2_GPIO_Port GPIOB
#define MOTOR_DMODE1_Pin GPIO_PIN_10
#define MOTOR_DMODE1_GPIO_Port GPIOB
#define MOTOR_DMODE0_Pin GPIO_PIN_11
#define MOTOR_DMODE0_GPIO_Port GPIOB
#define MOTOR1_ERR_Pin GPIO_PIN_14
#define MOTOR1_ERR_GPIO_Port GPIOB
#define MOTOR2_ERR_Pin GPIO_PIN_15
#define MOTOR2_ERR_GPIO_Port GPIOB
#define MOTOR2_PWM_Pin GPIO_PIN_6
#define MOTOR2_PWM_GPIO_Port GPIOC
#define MOTOR2_CW_Pin GPIO_PIN_7
#define MOTOR2_CW_GPIO_Port GPIOC
#define GYRO_IN_Pin GPIO_PIN_15
#define GYRO_IN_GPIO_Port GPIOA
#define SPI_CS_Pin GPIO_PIN_2
#define SPI_CS_GPIO_Port GPIOD
#define LED_B_Pin GPIO_PIN_3
#define LED_B_GPIO_Port GPIOB
#define LED_G_Pin GPIO_PIN_4
#define LED_G_GPIO_Port GPIOB
#define LED_R_Pin GPIO_PIN_5
#define LED_R_GPIO_Port GPIOB
#define SW_1_Pin GPIO_PIN_6
#define SW_1_GPIO_Port GPIOB
#define SW_2_Pin GPIO_PIN_7
#define SW_2_GPIO_Port GPIOB
#define SPEAKER_Pin GPIO_PIN_8
#define SPEAKER_GPIO_Port GPIOB

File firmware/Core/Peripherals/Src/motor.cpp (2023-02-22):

/*
 * motor.c
 *
 *  Created on: 2021/03/02
 *      Author: raku
 */

#include "main.h"
#include "motor.hpp"
#include "tools.hpp"

#include "arm_math.h"

extern DAC_HandleTypeDef hdac;
extern TIM_HandleTypeDef htim3;
extern TIM_HandleTypeDef htim8;



/**
 * @brief モーターの初期化関数
 * 
 */
void Motor::init(void){
	HAL_GPIO_WritePin(MOTOR_EN_GPIO_Port, MOTOR_EN_Pin, GPIO_PIN_SET); //enableをhighにして出力をon
	HAL_Delay(1);
	HAL_GPIO_WritePin(MOTOR_RESET_GPIO_Port, MOTOR_RESET_Pin, GPIO_PIN_RESET); //resetをlowにして電気角リセットから通常動作に
	HAL_Delay(1);
	HAL_GPIO_WritePin(MOTOR_DMODE0_GPIO_Port, MOTOR_DMODE0_Pin, GPIO_PIN_SET); //dmodeを8W1-2相励磁に
	HAL_GPIO_WritePin(MOTOR_DMODE1_GPIO_Port, MOTOR_DMODE1_Pin, GPIO_PIN_SET);
	HAL_GPIO_WritePin(MOTOR_DMODE2_GPIO_Port, MOTOR_DMODE2_Pin, GPIO_PIN_SET);

	HAL_DAC_Start(&hdac, DAC_CHANNEL_1);
	HAL_DAC_SetValue(&hdac, DAC_CHANNEL_1, DAC_ALIGN_8B_R, 50);

	set_cw(1, 1);
	//速度を0にする	
	TIM3->CCR3 = 0;
	TIM8->CCR1 = 0;
	HAL_TIM_PWM_Start(&htim3, TIM_CHANNEL_3);
	HAL_TIM_PWM_Start(&htim8, TIM_CHANNEL_1);
}

void Motor::enable(uint8_t state){
	HAL_GPIO_WritePin(MOTOR_EN_GPIO_Port, MOTOR_EN_Pin, static_cast<GPIO_PinState>(state)); //enableを設定
}

void Motor::set_vref(uint8_t v){
	HAL_DAC_SetValue(&hdac, DAC_CHANNEL_1, DAC_ALIGN_8B_R, v);
}

/**
 * @brief モーターの回転方向をセットする
 * 
 * @param cw_l 1-正転, 0-逆転 
 * @param cw_r 1-正転, 0-逆転  
 */
void Motor::set_cw(uint8_t cw_l, uint8_t cw_r){
	cw_r = !cw_r;
	HAL_GPIO_WritePin(MOTOR1_CW_GPIO_Port, MOTOR1_CW_Pin, static_cast<GPIO_PinState>(cw_l));
	HAL_GPIO_WritePin(MOTOR2_CW_GPIO_Port, MOTOR2_CW_Pin, static_cast<GPIO_PinState>(cw_r));
}

/**
 * @brief モーターの速度を指定する関数
 * @param speed_l 左の移動速度 mm/sでfを付ける
 * @param speed_r 右の移動速度 mm/sでfを付ける
 */
void Motor::set_speed(float32_t speed_l, float32_t speed_r){
	uint8_t cw[2] = {1, 1};
	if(speed_l < 0){
		cw[0] = 0;
		speed_l = -1 * speed_l;
	}
	if(speed_r < 0){
		cw[1] = 0;
		speed_r = -1 * speed_r;	
	} 
	set_cw(cw[0], cw[1]);

	//周期をusで計算する
	const float32_t period_l = 1000000.0f * radius * PI / 3200.0f / speed_l;
	const float32_t period_r = 1000000.0f * radius * PI / 3200.0f / speed_r;

	const int32_t period_us_l = static_cast<int32_t>(period_l);
	const int32_t period_us_r = static_cast<int32_t>(period_r);
	
	//左モーターのTIMのARRとCCR3を設定する
	TIM3->ARR = period_us_l - 1;
	TIM3->CCR3 = period_us_l / 2;

	//左モーターのTIMのARRとCCR3を設定する
	TIM8->ARR = period_us_r - 1;
	TIM8->CCR1 = period_us_r / 2;		
}

void Motor::update_speed(void){
	float32_t speed_l_toset = speedstate_l.current;
	float32_t speed_r_toset = speedstate_r.current;
	float32_t accel_dt = accel * t_scale;

	//目標値と現在値がずれている場合、一定の加速度だけ値を変化させる
	if(abs(speedstate_l.current - speedstate_l.target) < accel_dt){
		speed_l_toset = speedstate_l.target;
	}else if (speedstate_l.current < speedstate_l.target){
		speed_l_toset += accel_dt;
	}else if (speedstate_l.current > speedstate_l.target){
		speed_l_toset -= accel_dt;
	}
	
	if(abs(speedstate_r.current - speedstate_r.target) < accel_dt){
		speed_r_toset = speedstate_r.target;
	}else if (speedstate_r.current < speedstate_r.target){
		speed_r_toset += accel_dt;
	}else if (speedstate_r.current > speedstate_r.target){
		speed_r_toset -= accel_dt;
	}
	
	speedstate_l.previous = speedstate_l.current;
	speedstate_r.previous = speedstate_r.current;
	speedstate_l.current = speed_l_toset;
	speedstate_r.current = speed_r_toset;

	set_speed(speed_l_toset, speed_r_toset);
}

void Motor::set_target(float32_t speed_l, float32_t speed_r){
	speedstate_l.target =  speed_l;
	speedstate_r.target =  speed_r;		
}

void Motor::set_target_deg(float32_t deg_speed){
	float32_t speed = deg_speed_to_speed(deg_speed);
	speedstate_l.target =  speed;
	speedstate_r.target =  -1 * speed;	
}

void Motor::set_turn_speed(float32_t deg_speed){
	float32_t speed = deg_speed_to_speed(deg_speed);
	set_speed(speed, -1 * speed);
}

void Motor::stop(void){
	TIM3->CCR3 = 0;
	TIM8->CCR1 = 0;	
}

float32_t Motor::deg_speed_to_speed(float32_t deg_speed){
	return (tire_width / 2.0f) * deg_speed * PI / 180.0f;
}

float32_t Motor::speed_to_degspeed(float32_t speed){
	return (speed * 2.0f * 180.0f) /( tire_width * PI);
}

void Motor::forward(float32_t length, uint8_t slow_down){
	if(length < 80.0f){
		forward_speed = 180.0f;
	}else{
		forward_speed = 270.0f * forward_scale;
	}
	
	if(slow_down == 0){
		const float32_t gain = 0.99;
		state.delta_max = length * gain;
	}else{
		const float32_t gain = 1.00;
		state.delta_max = length * gain;
	}
	
	state.mode = state.forward;
	state.slow_down = slow_down;
	HAL_Delay(2);
	while (1){
		if(state.mode_lock == 0) break;
	}
}

void Motor::turn(float32_t deg){
	state.delta_max_deg = deg;
	state.mode = state.turn;
	HAL_Delay(2);
	while (1){
		if(state.mode_lock == 0) break;
	}
	HAL_Delay(2);
}

void Motor::kabeate0(void){
	forward(-70.0f);
	forward(40.5f);
}

void Motor::kabeate1(void){
	turn(-90.0f);
	kabeate0();
}

void Motor::kabeate2(void){
	turn(90.0f);
	kabeate0();
}

void Motor::kabeate_turn_l(void){
	turn(-90.0f);
	kabeate0();
	turn(-90.0f);
	kabeate0();
}
void Motor::kabeate_turn_r(void){
	turn(90.0f);
	kabeate0();
	turn(90.0f);
	kabeate0();
}

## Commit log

2022-11-04 README.mdにロボット画像を追加
2022-11-06 書き換えを行った。
2022-11-06 Mazelibraryをsubmoduleとして追加
2022-11-06 Mazelibraryを更新
2022-11-06 迷路関係についてはmazelibraryに任せることにした
2022-11-06 コンパイルができるようになったが、 has a LOAD segment with RWX permissions という警告も出た
2022-11-06 向きと見えた壁からマップ情報で使う壁を返す関数を作成した
2022-11-06 mazelibraryの更新を反映した
2022-11-06 コンパイルと動作を確認した 電流値を少し上げた
2022-11-13 とりあえず動いた。角度の補正が必要。
2022-11-13 ジャイロを使った補正を入れた
2022-11-18 3,3にゴールできた。壁補正を入れたい
2022-11-19 壁補正を無効化した
2022-11-20 回転をジャイロで行うようにした
2022-11-20 ゴールはできたが、step==3の帰り道でコケる
2022-12-25 大会の(たぶん)
2023-02-10 直進時にブレーキをかけない状態を作った。
2023-02-11 絶対パスになっており、フォルダ名まで異なっていたので更新
2023-02-11 うまく動かないため、makefile-toolsを使わないように変更
2023-02-11 プロトタイプ宣言と実体の宣言で両方デフォルト引数を定義していたエラーを修正
2023-02-11 flashのsector0に迷路データを保存できるように書き換え
2023-02-11 flashの読み書きを実装した
2023-02-14 jlinkで書き込みだけをできるようにした
2023-02-14 簡単な壁補正を入れた
2023-02-14 flashによる壁の保存を追加 探索を往復足立法に変更した
2023-02-14 省略可能なvoidを削除
2023-02-14 手法を往復足立法に変更した
2023-02-22 全日本2022の時のプログラム
2023-11-11 東日本大会のやつ

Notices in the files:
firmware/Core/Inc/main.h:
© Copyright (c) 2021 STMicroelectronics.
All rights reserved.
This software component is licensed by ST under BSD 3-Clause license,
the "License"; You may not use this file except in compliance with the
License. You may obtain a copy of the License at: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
